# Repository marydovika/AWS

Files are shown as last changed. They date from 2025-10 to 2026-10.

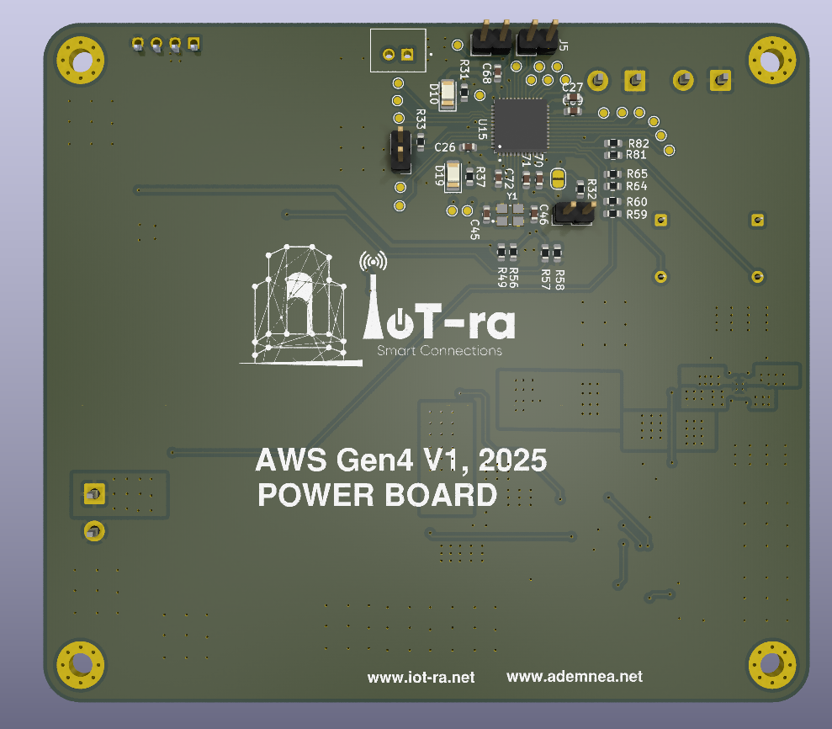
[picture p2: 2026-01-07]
IMAGES__Ver1/POWER BOARD images/Current design/BACK GREEN.png

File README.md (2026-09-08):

//////////////////////////////////////////////////////////////////////////////////////////////////

System Description:

Automatic Weather Stations (AWS) play a critical role in environmental monitoring, yet
their deployment in remote and energy-constrained locations remains limited by rigid and
monolithic power architectures.
Conventional systems are often designed for single energy sources, leading to inefficiencies, frequent power interruptions, high maintenance costs, and
poor adaptability to dynamic environmental conditions.
This research proposes the development of a modular and adaptive power electronics system architecture tailored for
energy-constrained AWS deployments.
Modular design;
The modular design introduces swappable converter topologies that allow scalable integration (multiplexing) of multiple energy sources,
including solar, DC input and  batteries, while simplifying upgrades, repairs, and fault isolation.
Adaptive design;
Complementing the modular design, an adaptive control strategy will be implemented to dynamically
optimize power flow in response to load variations, energy resource intermittency, in-system parameter drifts, and external/environmental
disturbances, thereby enhancing system stability and efficiency.
The study will involve system design, prototype development, and two algorithm development (both AMPC-based), followed by performance evaluation
under varying operating conditions and benchmarking. Field deployment of Final product (PCB, Case Unit, and Mounting frame).

Expected outcomes include;
improved system energy efficiency,
fault tolerance, and operational autonomy,
ensuring more reliable and sustainable weather data collection in energy resource-constrained and off-grid regions.
The findings of this research will contribute to advancing resilient power system solutions that support agriculture, public
safety, infrastructure planning, and climate research. with a civil and possible military adaptation.

Project is funded by:
https://www.ademneaproject.net

//////////////////////////////////////////////////////////////////////////////////////////////////

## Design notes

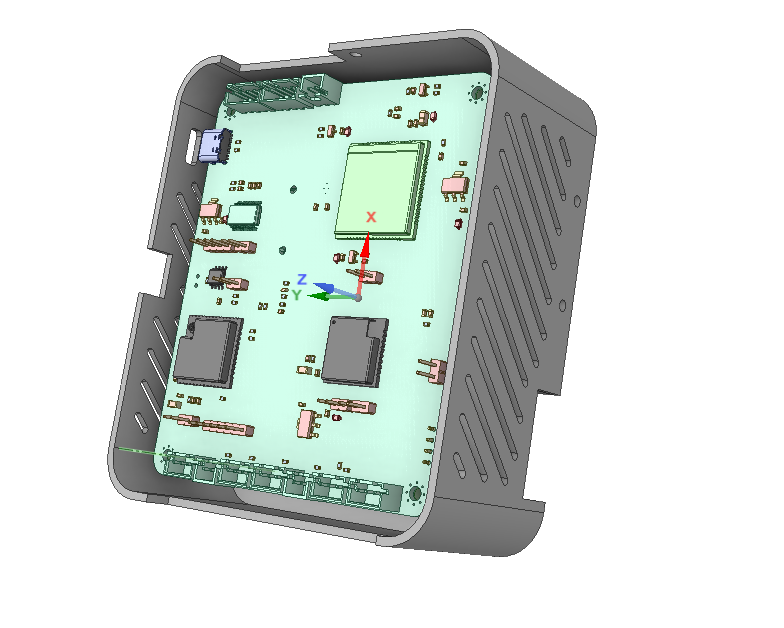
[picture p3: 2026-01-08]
IMAGES__Ver1/CASE DESIGN/design 2/Screenshot 2026-01-08 214305.png

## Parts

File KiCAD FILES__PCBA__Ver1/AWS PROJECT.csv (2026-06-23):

Reference | Qty | Value | DNP | Exclude from BOM | Exclude from Board | LCSC | Footprint | Datasheet
BT1 | 1 | BHX1-1225-PC |  |  |  | C6868959 | BHX1-1225-PC:BAT_BHX1-1225-PC
C1,C3,C30,C35,C61,C62 | 6 | 10uF |  |  |  | C19702 | Capacitor_SMD:C_0603_1608Metric | ~
C2,C4,C6,C11,C12,C13,C15,C18,C26,C27,C28,C33,C34 | 13 | 0.1uF |  |  |  | C14663 | Capacitor_SMD:C_0603_1608Metric | ~
C7,C8,C9,C16,C29,C31,C36,C63,C64 | 9 | 1uF |  |  |  | C15849 | Capacitor_SMD:C_0603_1608Metric | ~
C14 | 1 | 22uF |  |  |  | C12891 | Capacitor_SMD:C_1206_3216Metric_Pad1.33x1.80mm_HandSolder | ~
C17 | 1 | 100uF |  |  |  | C15008 | Capacitor_SMD:C_1206_3216Metric_Pad1.33x1.80mm_HandSolder | ~
C25,C47,C48 | 3 | 10uF |  |  |  | C89632 | Capacitor_SMD:C_1206_3216Metric_Pad1.33x1.80mm_HandSolder | CC0603KRX7R9BB103,~
C32 | 1 | 4.7uF |  |  |  | C1705 | Capacitor_SMD:C_0603_1608Metric | ~
C37,C49 | 2 | 2.2uF |  |  |  | C23630 | Capacitor_SMD:C_0603_1608Metric_Pad1.08x0.95mm_HandSolder | CC0603KRX7R9BB103
C38,C54 | 2 | 22pF |  |  |  | C92670 | Capacitor_SMD:C_0603_1608Metric_Pad1.08x0.95mm_HandSolder | CC0603KRX7R9BB103
C39 | 1 | 0.01uF |  |  |  | C100042 | Capacitor_SMD:C_0603_1608Metric_Pad1.08x0.95mm_HandSolder | CC0603KRX7R9BB103
C40,C41,C43,C53 | 4 | 1uF |  |  |  | C15849 | Capacitor_SMD:C_0603_1608Metric_Pad1.08x0.95mm_HandSolder | CC0603KRX7R9BB103
C42 | 1 | 0.1uf |  |  |  | C14663 | Capacitor_SMD:C_0603_1608Metric_Pad1.08x0.95mm_HandSolder | CC0603KRX7R9BB103
C44 | 1 | 10uF |  |  |  | C30110 | Capacitor_SMD:CP_Elec_5x5.8 | ~
C45 | 1 | 100nF |  |  |  | C24497 | Capacitor_SMD:C_1206_3216Metric_Pad1.33x1.80mm_HandSolder | CC1206KRX7R9BB104
C46 | 1 | 10nF |  |  |  | C100042 | Capacitor_SMD:C_0603_1608Metric_Pad1.08x0.95mm_HandSolder | CC0603KRX7R9BB103
C50 | 1 | 0.1uF |  |  |  | C14663 | Capacitor_SMD:C_0603_1608Metric_Pad1.08x0.95mm_HandSolder | CC0603KRX7R9BB103
C55 | 1 | 2.7nF |  |  |  | C107085 | Capacitor_SMD:C_0603_1608Metric | 0603B272K500NT
C56,C59,C60 | 3 | 22uF |  |  |  | C86295 | Capacitor_SMD:C_0603_1608Metric_Pad1.08x0.95mm_HandSolder | CL10A226MO7JZNC
C57 | 1 | 10uF |  |  |  | C89632 | Capacitor_SMD:C_1210_3225Metric_Pad1.33x2.70mm_HandSolder | CC0603KRX7R9BB103
C58 | 1 | 33pF |  |  |  | C107047 | Capacitor_SMD:C_0603_1608Metric | CC0603JRNPO9BN330
C65 | 1 | 0.1uF |  |  |  | C66501 | Capacitor_SMD:C_0603_1608Metric | ~
C66 | 1 | 10nF |  |  |  | C1589 | Capacitor_SMD:C_0603_1608Metric | ~
C67 | 1 | 0.1uF |  |  |  | C1592 | Capacitor_SMD:C_0603_1608Metric | ~
C68,C71 | 2 | 4.7uF |  |  |  | C19666 | Capacitor_SMD:C_0603_1608Metric | ~
C69,C70 | 2 | 0.1uF |  |  |  | C1589 | Capacitor_SMD:C_0603_1608Metric | ~
C72,C73 | 2 | 22pF |  |  |  | C92670 | Capacitor_SMD:C_0603_1608Metric | ~
D1,D2,D15,D16 | 4 | 1N5819WS |  |  | Excluded from board | C191023 | Diode_SMD:D_SOD-323 | https://datasheet.lcsc.com/lcsc/2204281430_Guangdong-Hottech-1N5819WS_C191023.pdf
D3,D4,D7,D22 | 4 | PESDHC3D3V3U |  |  |  | C41376407 | Diode_SMD:D_SOD-323F | https://www.lcsc.com/datasheet/lcsc_datasheet_2409191648_hongjiacheng-SMAJ10A_C41376407.pdf
D5,D8,D9,D11,D13,D14,D17,D18,D19,D20 | 10 | NET_LED |  |  |  | C22371297 | Diode_SMD:D_0603_1608Metric | ~
D6 | 1 | ESDA6V1W5 |  |  |  | C48677 | ESDA6V1W5:SOT65P210X110-5N
D21,D23 | 2 | B540C-13-F |  |  |  | C72264 | Diode_SMD:D_SMB-SMC_Universal_Handsoldering | ~
D24 | 1 | green |  |  |  | C2980185 | LED_SMD:LED_1206_3216Metric | ~
D25 | 1 | red |  |  |  | C28310439 | LED_SMD:LED_1206_3216Metric | ~
FB1 | 1 | FerriteBead_Small |  |  |  | C3764553 | BLM03HG601SZ1D:BEADC0603X33N | ~
GSM1,GSM2 | 2 | U.FL-R-SMT(10) |  |  |  | C434808 | Connector_Coaxial:U.FL_Molex_MCRF_73412-0110_Vertical
J7 | 1 | 104224-0820 |  |  |  | C585349 | 104224-0820:MOLEX_104224-0820
J16 | 1 | 503398-1892 |  |  |  | C428492 | 503398-1892:MOLEX_503398-1892
J24 | 1 | TYPE-C-31-M-12 |  |  |  | C165948 | TYPE-C-31-M-12:HRO_TYPE-C-31-M-12
L1 | 1 | 6.1uH |  |  |  | C2454102 | MPPT INDUCTORS:CDEP147NP-6R1MC-95 | ~
L2 | 1 | SRN6045TA-3R3Y |  |  |  | C3221229 | Inductor_SMD:L_Bourns_SRN6045TA | SRN6045TA-3R3Y
Q1,Q2,Q3 | 3 | MMBT3904 |  |  |  | C242260 | Package_TO_SOT_SMD:SOT-23 | https://www.onsemi.com/pdf/datasheet/pzt3904-d.pdf
Q4,Q7 | 2 | 2N7002 |  |  |  | C8545 | PCM_JLCPCB:Q_SOT-23 | https://www.lcsc.com/datasheet/lcsc_datasheet_2304140030_Jiangsu-Changjing-Electronics-Technology-Co---Ltd--2N7002_C8545.pdf
Q5,Q6 | 2 | NMOS |  |  |  | C604579 | NTMFS4H01NFT3G:TRANS_NVMFS5834NLWFT1G | https://ngspice.sourceforge.io/docs/ngspice-html-manual/manual.xhtml#cha_MOSFETs
R1,R24 | 2 | 0R |  |  |  | C95177 | Resistor_SMD:R_0603_1608Metric | ~
R2,R3,R5,R6,R7,R8,R13,R14,R20,R21,R25,R26,R32,R33,R38 | 15 | 4.7k |  |  |  | C99782 | Resistor_SMD:R_0603_1608Metric | ~
R4,R10,R12,R30,R34 | 5 | 10k |  |  |  | C98220 | Resistor_SMD:R_0603_1608Metric | ~
R9,R15,R16,R23,R29,R31,R35 | 7 | 1k |  |  |  | C22548 | Resistor_SMD:R_0603_1608Metric | ~
R36 | 1 | 20K |  |  |  | C105575 | Resistor_SMD:R_0603_1608Metric | ~
R37,R54,R55,R69,R71,R73,R75,R77,R79,R80,R82 | 11 | 10K |  |  |  | C98220 | Resistor_SMD:R_0603_1608Metric | ~
R39 | 1 | 120 |  |  |  | C22787 | Resistor_SMD:R_0603_1608Metric | ~
R40,R41 | 2 | 5.1k |  |  |  | C2907044 | Resistor_SMD:R_0603_1608Metric | ~
R42,R43 | 2 | 270R |  |  |  | C2907020 | Resistor_SMD:R_0603_1608Metric | ~
R44,R45 | 2 | 3.9 |  |  |  | C2930150 | Resistor_SMD:R_0603_1608Metric | ~
R46,R48 | 2 | 23.7k |  |  |  | C22912 | Resistor_SMD:R_0603_1608Metric_Pad0.98x0.95mm_HandSolder | FRC0603F5101TS
R47,R49 | 2 | 5k |  |  |  | C2828621 | Resistor_SMD:R_0603_1608Metric_Pad0.98x0.95mm_HandSolder | FRC0603F5101TS
R50 | 1 | 499K |  |  |  | C26751 | Resistor_SMD:R_0603_1608Metric | ~
R51 | 1 | 36K |  |  |  | C2930097 | Resistor_SMD:R_0603_1608Metric | ~
R52 | 1 | 25k |  |  |  | C2828637 | Resistor_SMD:R_0603_1608Metric | ~
R53 | 1 | 51.1K |  |  |  | C2933234 | Resistor_SMD:R_0603_1608Metric_Pad0.98x0.95mm_HandSolder | FRC0603F5101TS
R56 | 1 | 5.23k |  |  |  | C2930111 | Resistor_SMD:R_0603_1608Metric | ~
R57 | 1 | 7.5k |  |  |  | C2930127 | Resistor_SMD:R_0603_1608Metric | ~
R58 | 1 | 10 |  |  |  | C109318 | Resistor_SMD:R_0603_1608Metric | ~
R59 | 1 | 100 |  |  |  | C105588 | Resistor_SMD:R_0603_1608Metric | ~
R60 | 1 | 2.2 |  |  |  | C22939 | Resistor_SMD:R_0603_1608Metric | ~
R61 | 1 | 10 |  |  |  | C2933875 | Resistor_SMD:R_1812_4532Metric | ~
R62,R63,R65 | 3 | 5K1 |  |  |  | C2907044 | Resistor_SMD:R_0603_1608Metric_Pad0.98x0.95mm_HandSolder | FRC0603F5101TS
R64 | 1 | 4.22M |  |  |  | C3009313 | Resistor_SMD:R_0603_1608Metric | ~
R66 | 1 | 154k |  |  |  | C861677 | Resistor_SMD:R_0603_1608Metric | ~
R67 | 1 | 887k |  |  |  | C5126163 | Resistor_SMD:R_0603_1608Metric | ~
R68 | 1 | 162k |  |  |  | C2998114 | Resistor_SMD:R_0603_1608Metric | ~
R70 | 1 | 20k |  |  |  | C105575 | Resistor_SMD:R_0603_1608Metric | ~
R72 | 1 | 13k |  |  |  | C2906992 | Resistor_SMD:R_0603_1608Metric | ~
R74 | 1 | 1.5K |  |  |  | C22843 | Resistor_SMD:R_0603_1608Metric | ~
R76 | 1 | 2k |  |  |  | C22975 | Resistor_SMD:R_0603_1608Metric | ~
R78 | 1 | 1.2K |  |  |  | C2906976 | Resistor_SMD:R_0603_1608Metric | ~
R81 | 1 | 330 |  |  |  | C23138 | Resistor_SMD:R_0603_1608Metric | ~
TH1 | 1 | 100k |  |  |  | C5146262 | Resistor_SMD:R_1812_4532Metric | ~
U1,U2,U10,U12,U17 | 5 | AMS1117-3.3 |  |  |  | C6186 | Package_TO_SOT_SMD:SOT-223-3_TabPin2 | http://www.advanced-monolithic.com/pdf/ds1117.pdf
U3 | 1 | TXB0108RGYR |  |  |  | C194701 | TXB0108RGYR:IC_TXB0108RGYR
U4 | 1 | ESP32-WROOM-32E__4MB_HIGH_TEMP_ |  |  |  | C701344 | ESP32-WROOM-32UE_M113EH6400UH3Q0_:MODULE_ESP32-WROOM-32UE_M113EH6400UH3Q0_
U5 | 1 | SIM7000E |  |  |  | C126272 | SIM7000E:SIMCON_SIM7000E
U8 | 1 | DS3231MZ_TRL |  |  |  | C107410 | DS3231MZ_TRL:SOIC127P600X175-8N
U9 | 1 | Ai-Thinker RA-08H |  |  |  | C2991932 | RA-08H-Ai-Thinker-Symbol-Kicad-88998:RA-08H | https://docs.ai-thinker.com/_media/lora/docs/ra-08h_v1.1.0_specification.pdf
U11 | 1 | ST3485EBDR |  |  |  | C75809 | ST3485EBDR:SOIC127P600X175-8N
U13 | 1 | FT232RL-REEL |  |  |  | C8690 | FT232RL-REEL:SOP65P780X200-28N
U14 | 1 | BQ24650RVAR |  |  |  | C53712 | BQ24650RVAR:QFN50P350X350X100-17N
U15 | 1 | TPS2121RUXR |  |  |  | C485916 | TPS2121RUXR:IC_TPS2121RUXR
U16 | 1 | AP64501SP-13 |  |  |  | C2071517 | AP64501SP-13:SOIC127P600X170-9N | AP64501SP-13
U18 | 1 | STM32F401CCU6 |  |  |  | C79861 | STM32F401CCU6 (1):QFN50P700X700X60-49N
Y1 | 1 | C3E-25.000-12-3030-X-R |  |  |  | C5567192 | C3E-25.000-12-3030-X-R:XTAL_C3E-25.000-12-3030-X-R

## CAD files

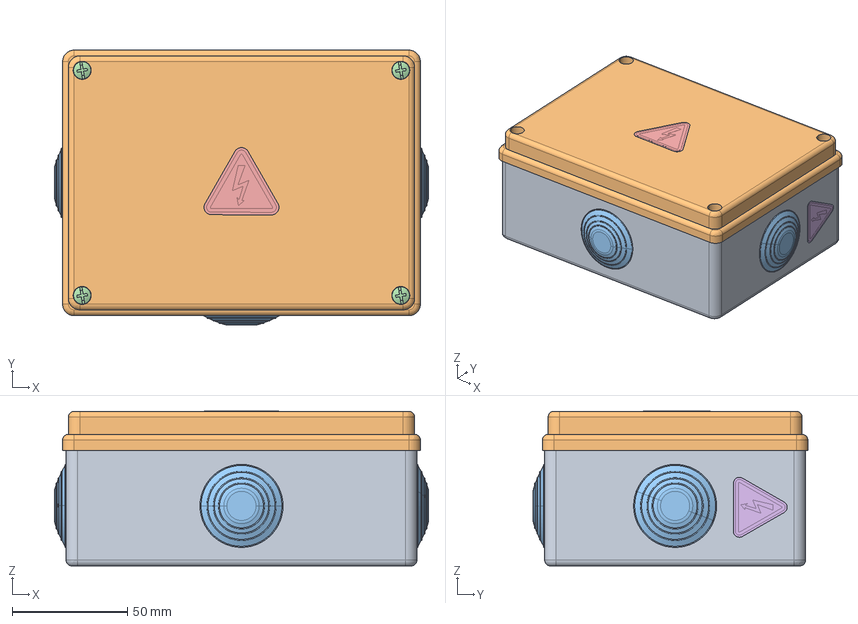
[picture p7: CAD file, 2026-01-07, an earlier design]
CAD MODELS__Ver1/junction-box-32/junction_box_asm.stp
162.0 x 119.0 x 67.1 mm
JUNCTION_BOX
JUNCTION_BOX_COVER
JUNCTION_BOX_RUBBER x 3
JUNCTION_BOX_SCREW x 4
STICKER_1
STICKER_2

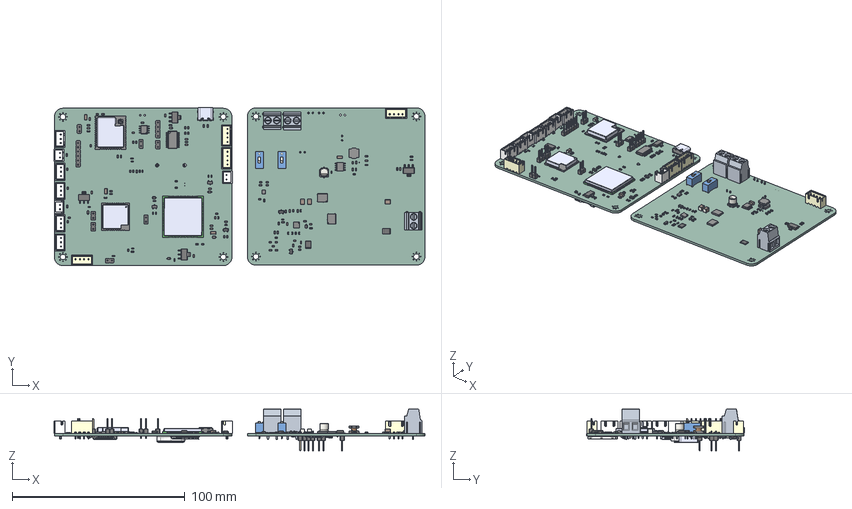
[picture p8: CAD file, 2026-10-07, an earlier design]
CAD MODELS__Ver1/AWS PROJECT 3D files.step
215.1 x 91.7 x 24.2 mm
D_SOD-323F x 4
R_0603_1608Metric x 75
PinHeader_1x02_P2.54mm_Vertical x 11
C_0603_1608Metric x 60
R_1812_4532Metric x 2
B3B-XH-A_LF__SN_ x 5
C_1210_3225Metric x 3
D_0603_1608Metric x 10
C_1206_3216Metric x 4
B4B-XH-A_LF__SN_ x 4
D_SOD-323 x 4
TB007-508-02P_Blue - S x 3
Q_SOT-23 x 2
SIM7000E
ST3485EBDR
SW_DIP_SPSTx01_Slide_9.78x4.72mm_W7.62mm_P2.54mm x 2
BQ24650RVAR
SOT-223 x 5
RA-08H--3DModel-STEP-269445
B2B-XH-A_LF__SN_ x 3
CP_Elec_5x5.8
L_Bourns_SRN6045TA
FT232RL-REEL
NTMFS4H01NFT3G x 2
PinHeader_1x06_P2.54mm_Vertical
PinHeader_1x04_P2.54mm_Vertical
SOT-23 x 3
C_0201_0603Metric
TYPE-C-31-M-12
TPS2121RUXR
ESP32-WROOM-32UE_M113EH6400UH3Q0_
AP64501SP-13
STM32F401CCU6
BHX1-1225-PC
LED_1206_3216Metric x 2
MEM2067-02-180-00-A_REVB
AWS PROJECT_PCB_1
AWS PROJECT_PCB_2

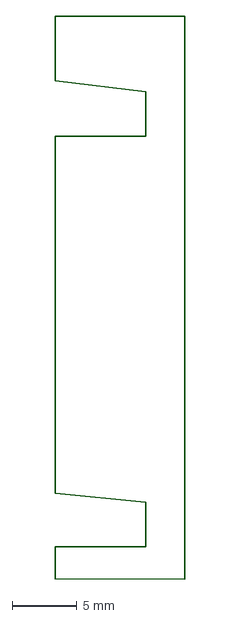
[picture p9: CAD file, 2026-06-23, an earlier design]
CAD MODELS__Ver1/prototype panel seperators/seperator.dxf
10.0 x 43.4 mm

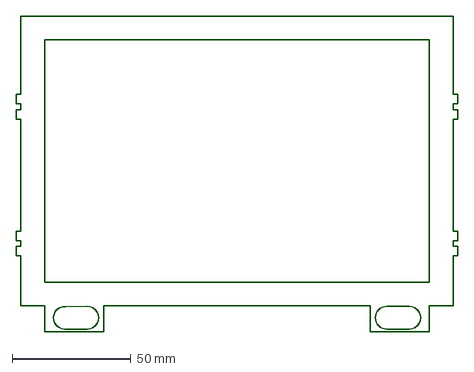
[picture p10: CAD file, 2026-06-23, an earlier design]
CAD MODELS__Ver1/prototype panel seperators/gateway acrilic.dxf
186.0 x 133.0 mm

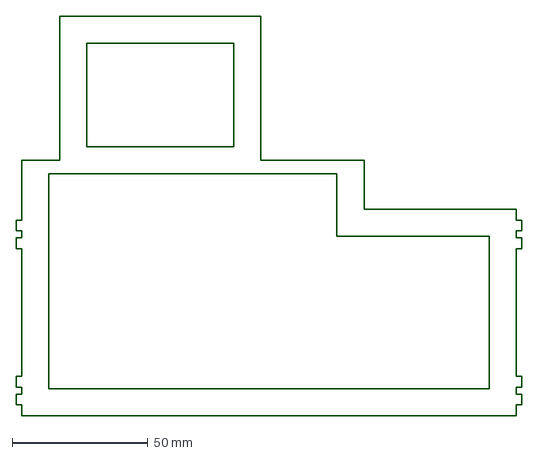
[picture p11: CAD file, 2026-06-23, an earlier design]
CAD MODELS__Ver1/prototype panel seperators/power acrilic.dxf
186.0 x 147.0 mm

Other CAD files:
CAD MODELS__Ver1/AWS PROJECT 3D ver2 files.step
CAD MODELS__Ver1/prototype panel seperators/seperator AWS.dwg

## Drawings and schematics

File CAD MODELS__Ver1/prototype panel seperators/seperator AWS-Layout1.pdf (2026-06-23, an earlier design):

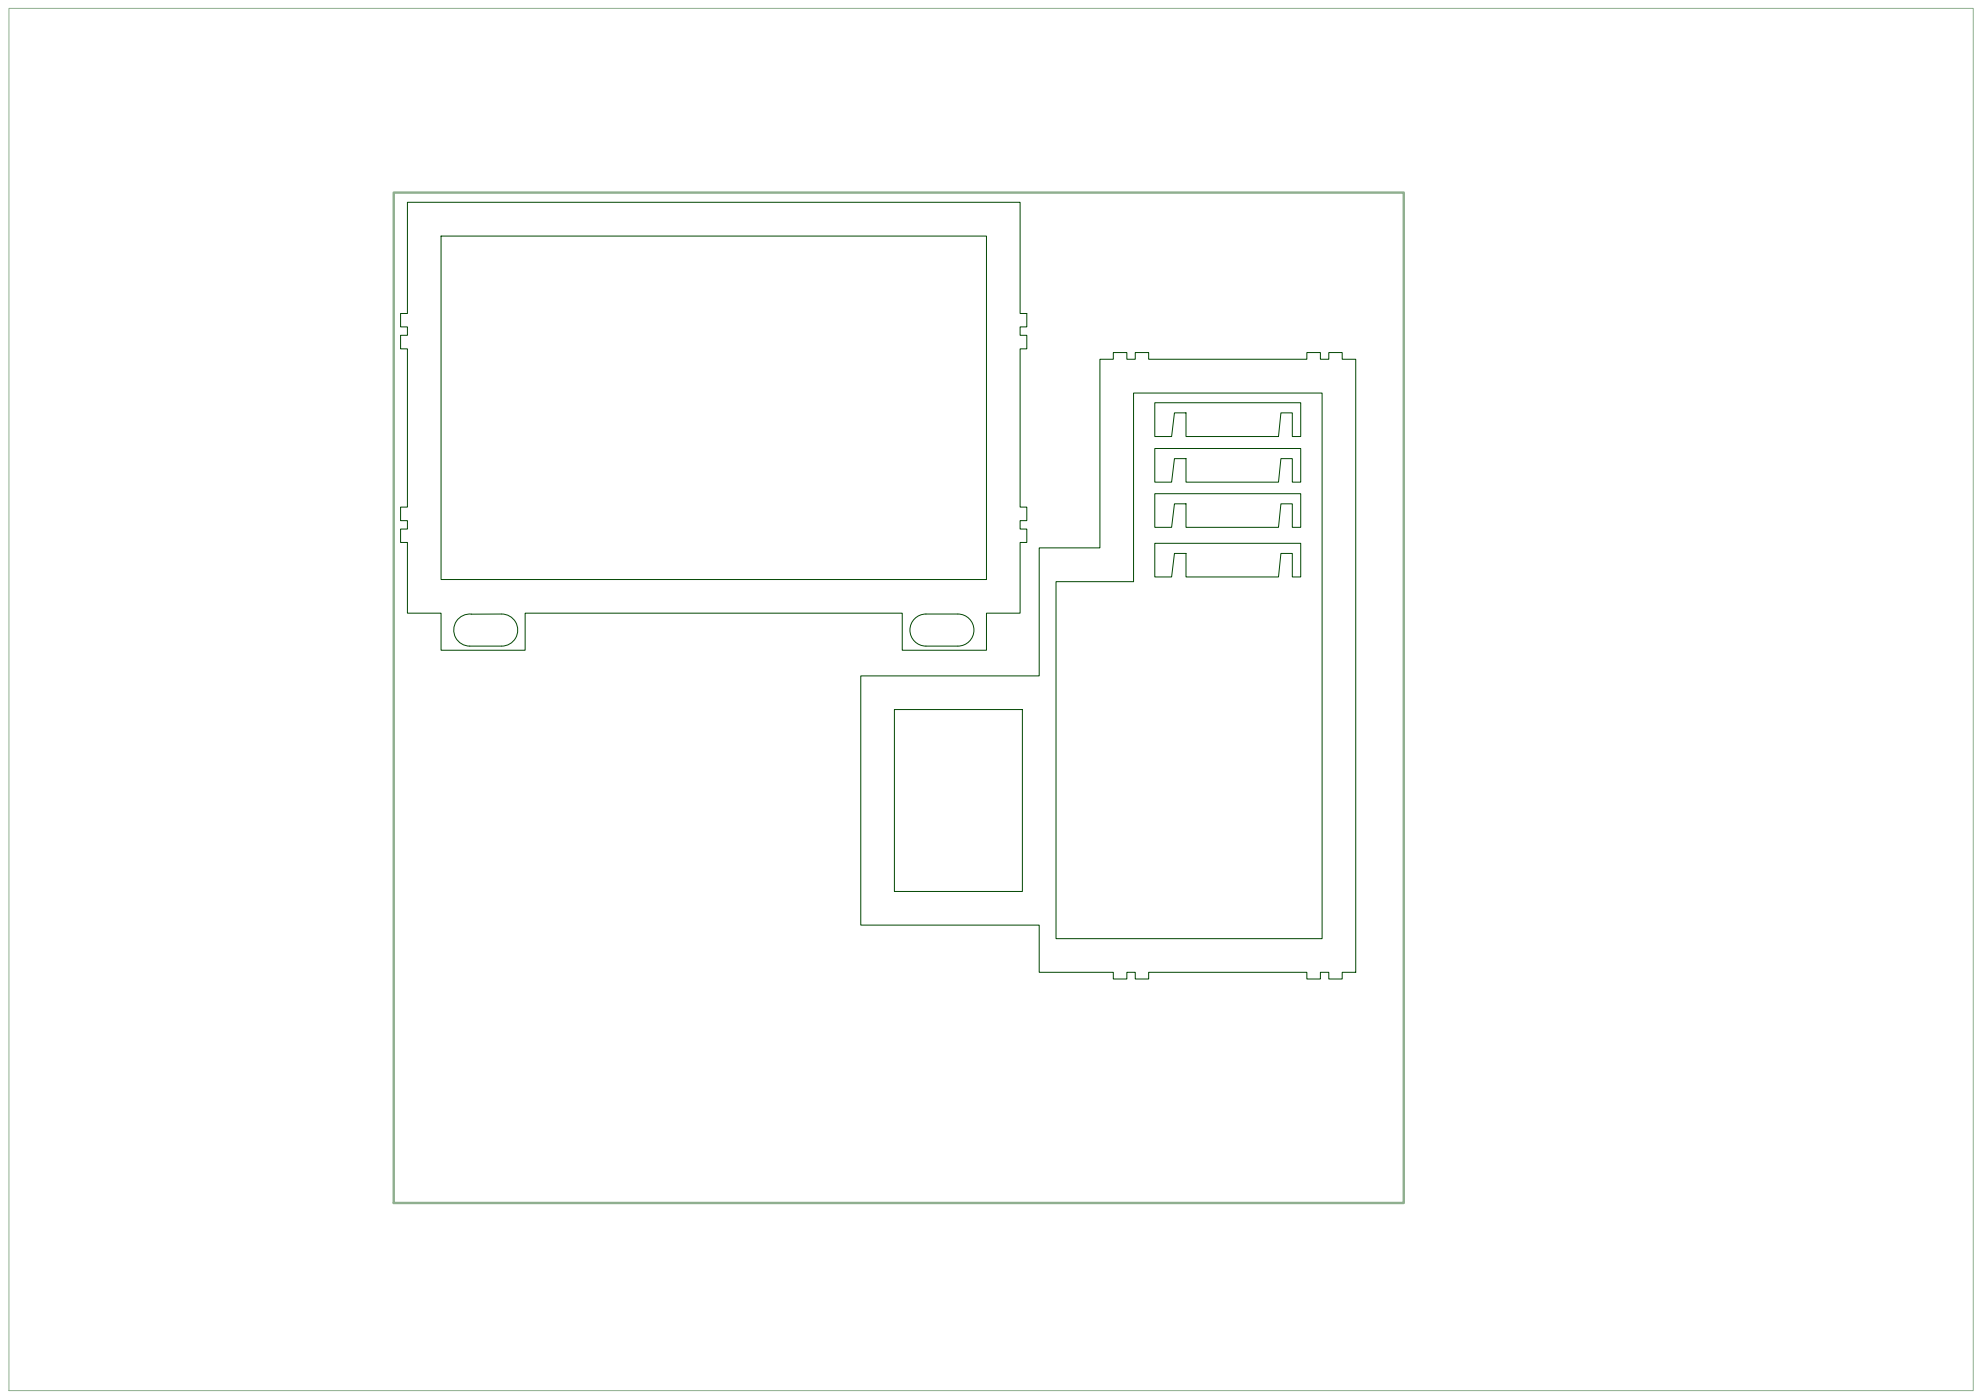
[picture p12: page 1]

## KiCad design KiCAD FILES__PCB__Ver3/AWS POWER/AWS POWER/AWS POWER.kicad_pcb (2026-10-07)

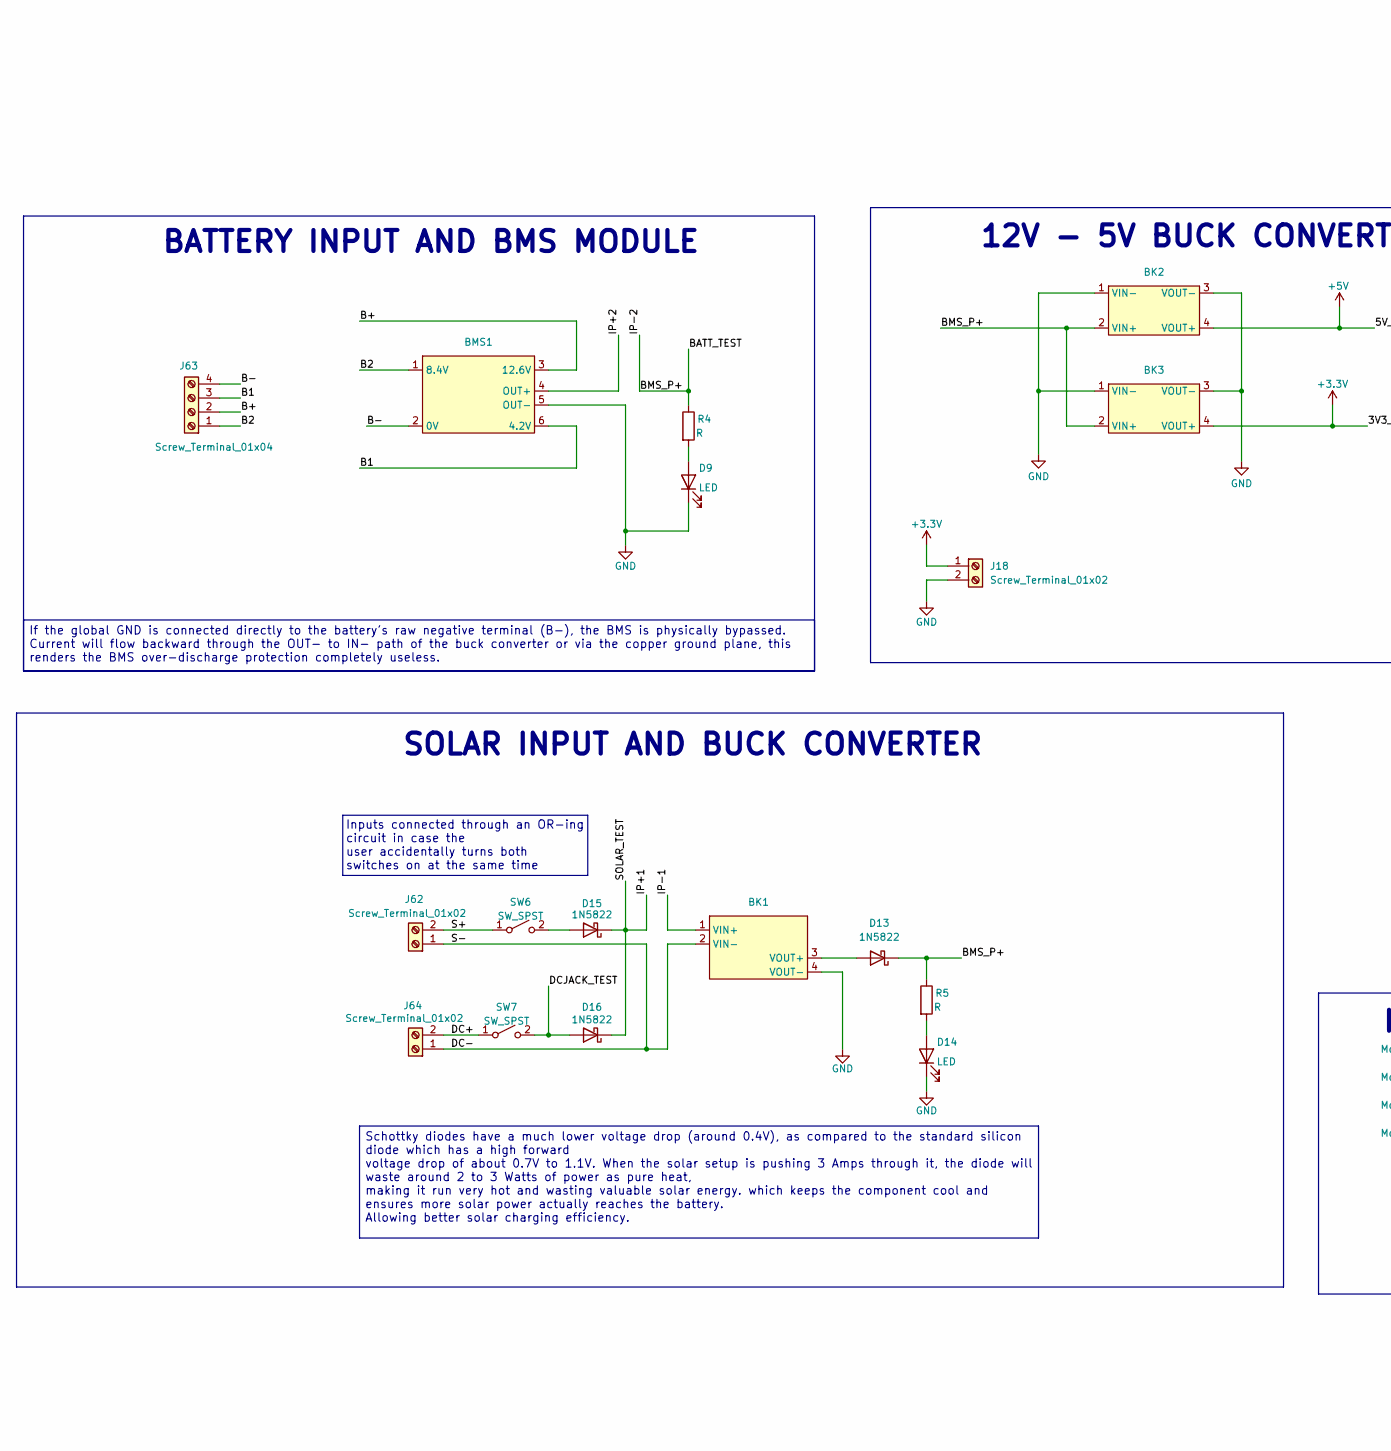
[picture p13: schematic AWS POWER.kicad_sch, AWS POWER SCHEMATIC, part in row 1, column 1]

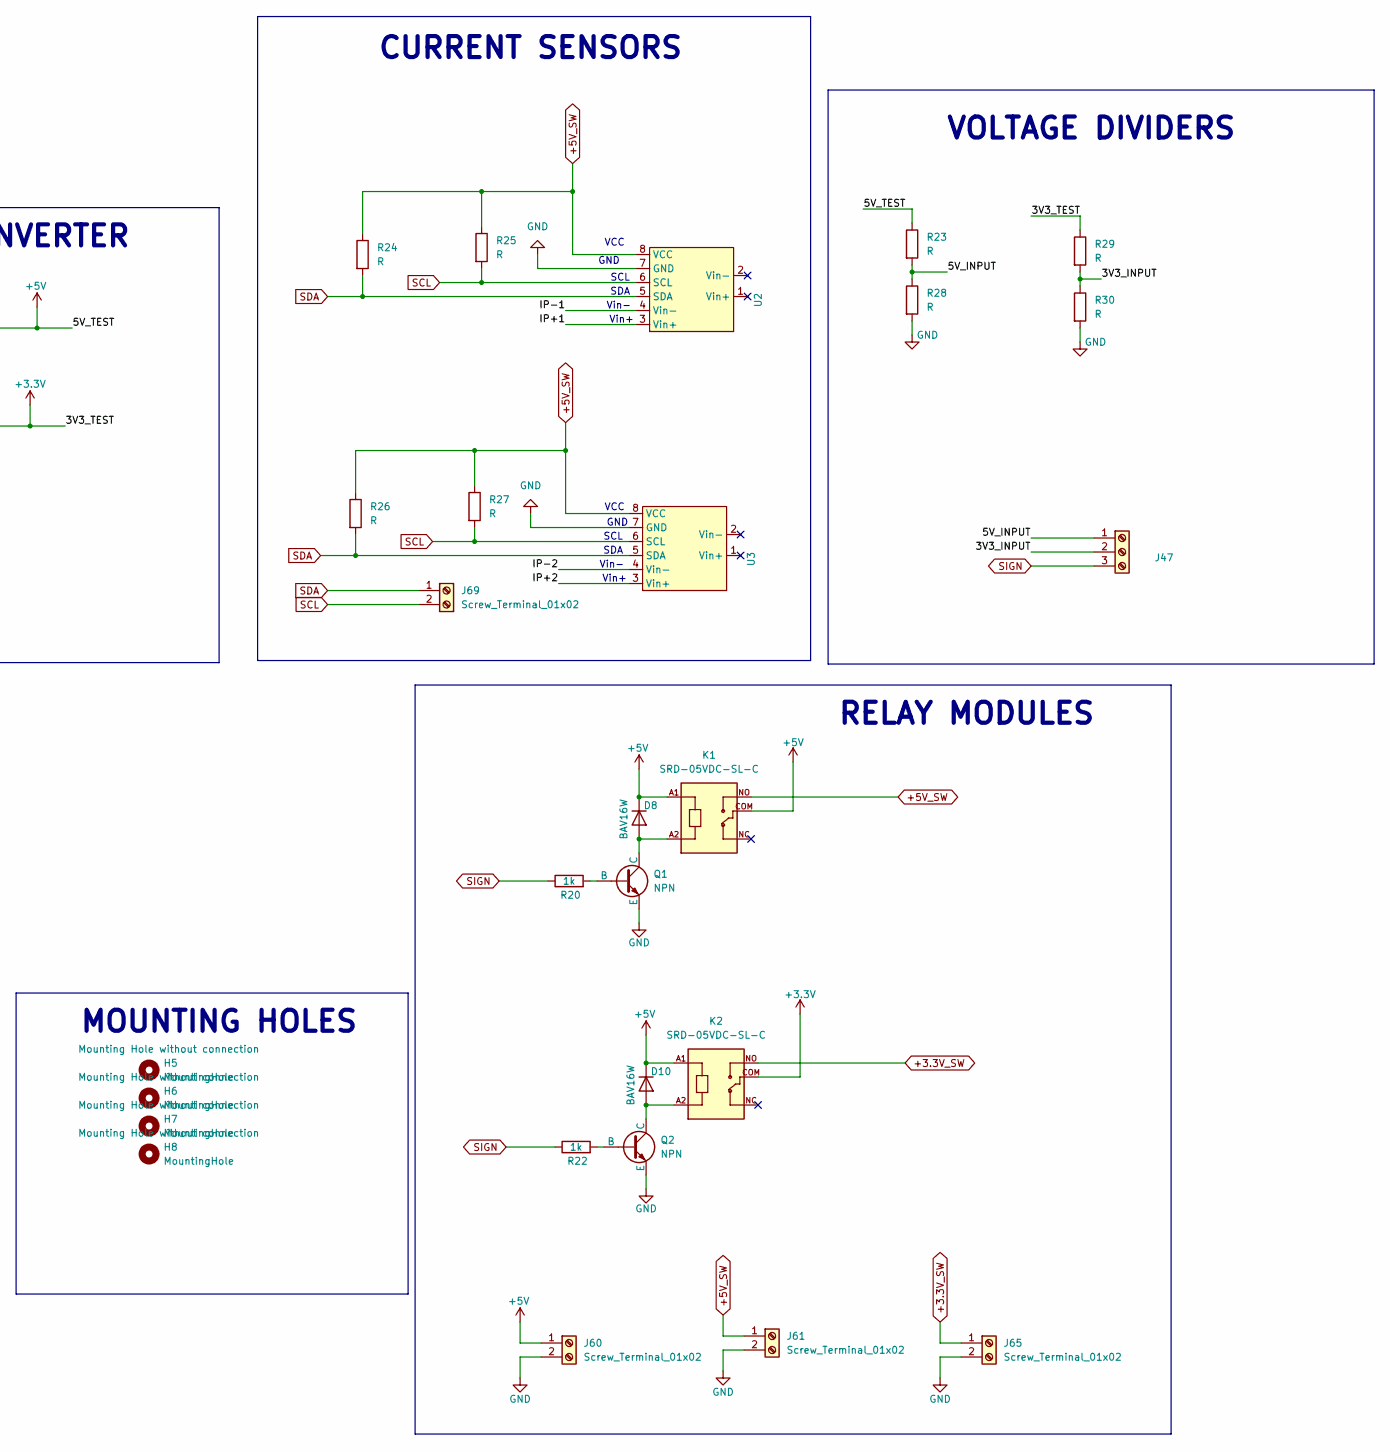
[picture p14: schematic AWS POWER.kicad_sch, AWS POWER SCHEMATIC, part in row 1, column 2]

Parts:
BK1: cn4015-2_module
BK2, BK3: MP1584 MODULE
BMS1: 3S 40A BMS
D8, D10: BAV16W; D_DO-201AD_P15.24mm_Horizontal; LCSC C459527
D9, D14: LED; LED_D3.0mm
D13, D15, D16: 1N5822; D_DO-201AD_P15.24mm_Horizontal
H5, H6, H7, H8: MountingHole; MountingHole_3.2mm_M3_DIN965_Pad_TopOnly
J18, J60, J61, J62, J64, J65, J69: Screw_Terminal_01x02; TerminalBlock_MetzConnect_Type055_RT01502HDWU_1x02_P5.00mm_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
J47: Screw_Terminal_01x03; TerminalBlock_Phoenix_MKDS-1-3-3.81_1x03_P3.81mm_Horizontal
J63: Screw_Terminal_01x04; TerminalBlock_MetzConnect_Type055_RT01504HDWU_1x04_P5.00mm_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
K1, K2: SRD-05VDC-SL-C; RELAY_SRD-05VDC-SL-C; LCSC C35449
Q1, Q2: NPN; TO-92; LCSC C52801
R4, R5, R23, R24, R25, R26, R27, R28, R29, R30: R; R_Axial_DIN0207_L6.3mm_D2.5mm_P7.62mm_Horizontal
R20, R22: 1k; R_Axial_DIN0207_L6.3mm_D2.5mm_P7.62mm_Horizontal; LCSC C22548
SW6, SW7: SW_SPST; SW_DIP_SPSTx01_Slide_9.78x4.72mm_W7.62mm_P2.54mm
U2, U3: INA219 MODULE

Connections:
+3.3V: BK3.4 (VOUT+), J18.1, K2.COM, R29.1
+3.3V_SW: J65.1, K2.NO
+5V: BK2.4 (VOUT+), D8.1 (K), D10.1 (K), J60.1, K1.A1, K1.COM, K2.A1, R23.1
+5V_SW: J61.1, K1.NO, R24.1, R25.1, R26.1, R27.1, U2.8 (VCC), U3.8 (VCC)
/3V3_INPUT: J47.2, R29.2, R30.1
/5V_INPUT: J47.1, R23.2, R28.1
/B1: BMS1.6 (4.2V), J63.3
/B2: BMS1.1 (8.4V), J63.1
/B+: BMS1.3 (12.6V), J63.2
/B-: BMS1.2 (0V), J63.4
/BATT_TEST: BK2.2 (VIN+), BK3.2 (VIN+), D13.1 (K), R4.1, R5.1, U3.4 (Vin-)
/DC+: J64.2, SW7.1 (A)
/DC-: BK1.2 (VIN-), J62.1, J64.1
/DCJACK_TEST: D16.2 (A), SW7.2 (B)
/IP+1: D15.1 (K), D16.1 (K), U2.3 (Vin+)
/IP+2: BMS1.4 (OUT+), U3.3 (Vin+)
/IP-1: BK1.1 (VIN+), U2.4 (Vin-)
/S+: J62.2, SW6.1 (A)
GND: BK1.4 (VOUT-), BK2.1 (VIN-), BK2.3 (VOUT-), BK3.1 (VIN-), BK3.3 (VOUT-), BMS1.5 (OUT-), D9.1 (K), D14.1 (K), J18.2, J60.2, J61.2, J65.2, Q1.3 (E), Q2.3 (E), R28.2, R30.2, U2.7 (GND), U3.7 (GND)
unnamed: BK1.3 (VOUT+), D13.2 (A)
unnamed: D8.2 (A), K1.A2, Q1.1 (C)
unnamed: D9.2 (A), R4.2
unnamed: D10.2 (A), K2.A2, Q2.1 (C)
unnamed: D14.2 (A), R5.2
unnamed: D15.2 (A), SW6.2 (B)
unnamed: Q1.2 (B), R20.2
unnamed: Q2.2 (B), R22.2
SCL: J69.2, R25.2, R27.2, U2.6 (SCL), U3.6 (SCL)
SDA: J69.1, R24.2, R26.2, U2.5 (SDA), U3.5 (SDA)
SIGN: J47.3, R20.1, R22.1

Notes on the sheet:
SCL
CURRENT SENSORS
Inputs connected through an OR-ing circuit in case the user accidentally turns both switches on at the same time
MOUNTING HOLES
BATTERY INPUT AND BMS MODULE
VOLTAGE DIVIDERS
GND
SOLAR INPUT AND BUCK CONVERTER
SDA
VCC
Vin-
Vin+
RELAY MODULES
12V - 5V BUCK CONVERTER
Schottky diodes have a much lower voltage drop (around 0.4V), as compared to the standard silicon diode which has a high forward voltage drop of about 0.7V to 1.1V. When the solar setup is pushing 3 Amps through it, the diode will waste around 2 to 3 Watts of power as pure heat, making it run very 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
If the global GND is connected directly to the battery's raw negative terminal (B-), the BMS is physically bypassed. Current will flow backward through the OUT- to IN- path of the buck converter or via the copper ground plane, this renders the BMS over-discharge protection completely useless.

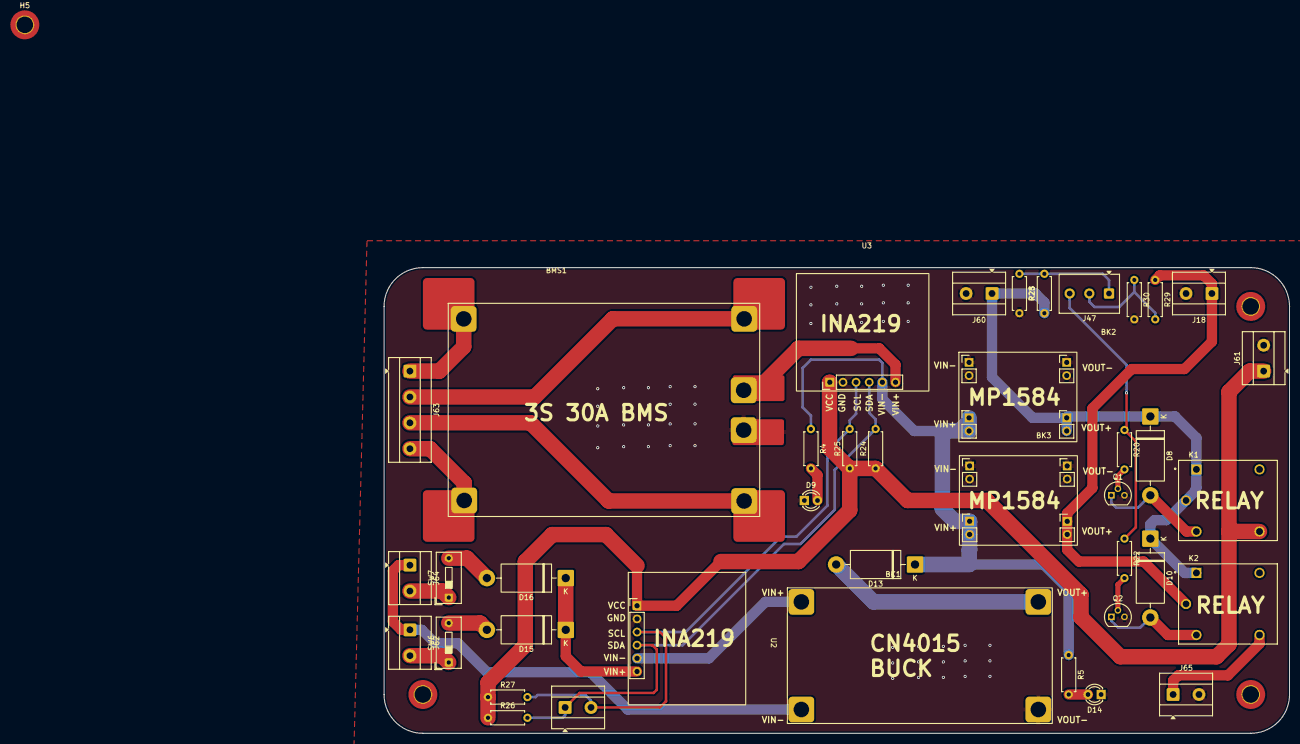
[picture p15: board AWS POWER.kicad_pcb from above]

Board: 2 copper layers, 175.0 x 90.0 mm, 44 parts (0 on the bottom side), 30 nets.

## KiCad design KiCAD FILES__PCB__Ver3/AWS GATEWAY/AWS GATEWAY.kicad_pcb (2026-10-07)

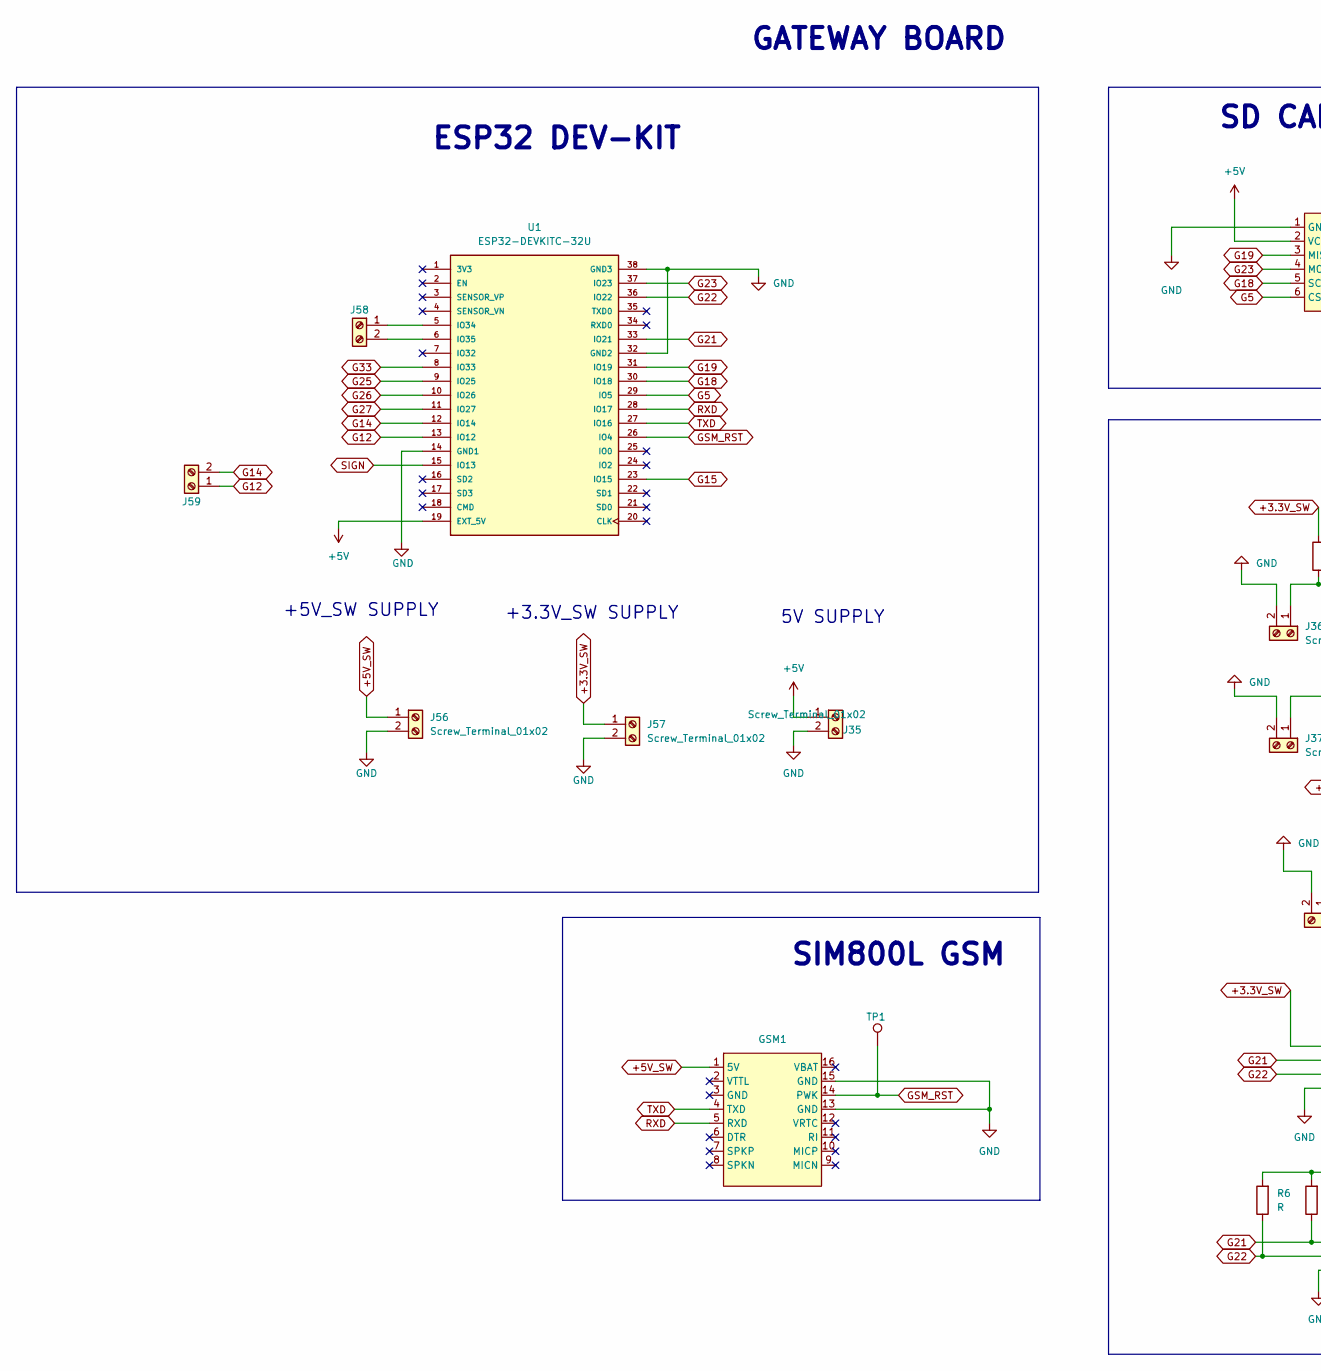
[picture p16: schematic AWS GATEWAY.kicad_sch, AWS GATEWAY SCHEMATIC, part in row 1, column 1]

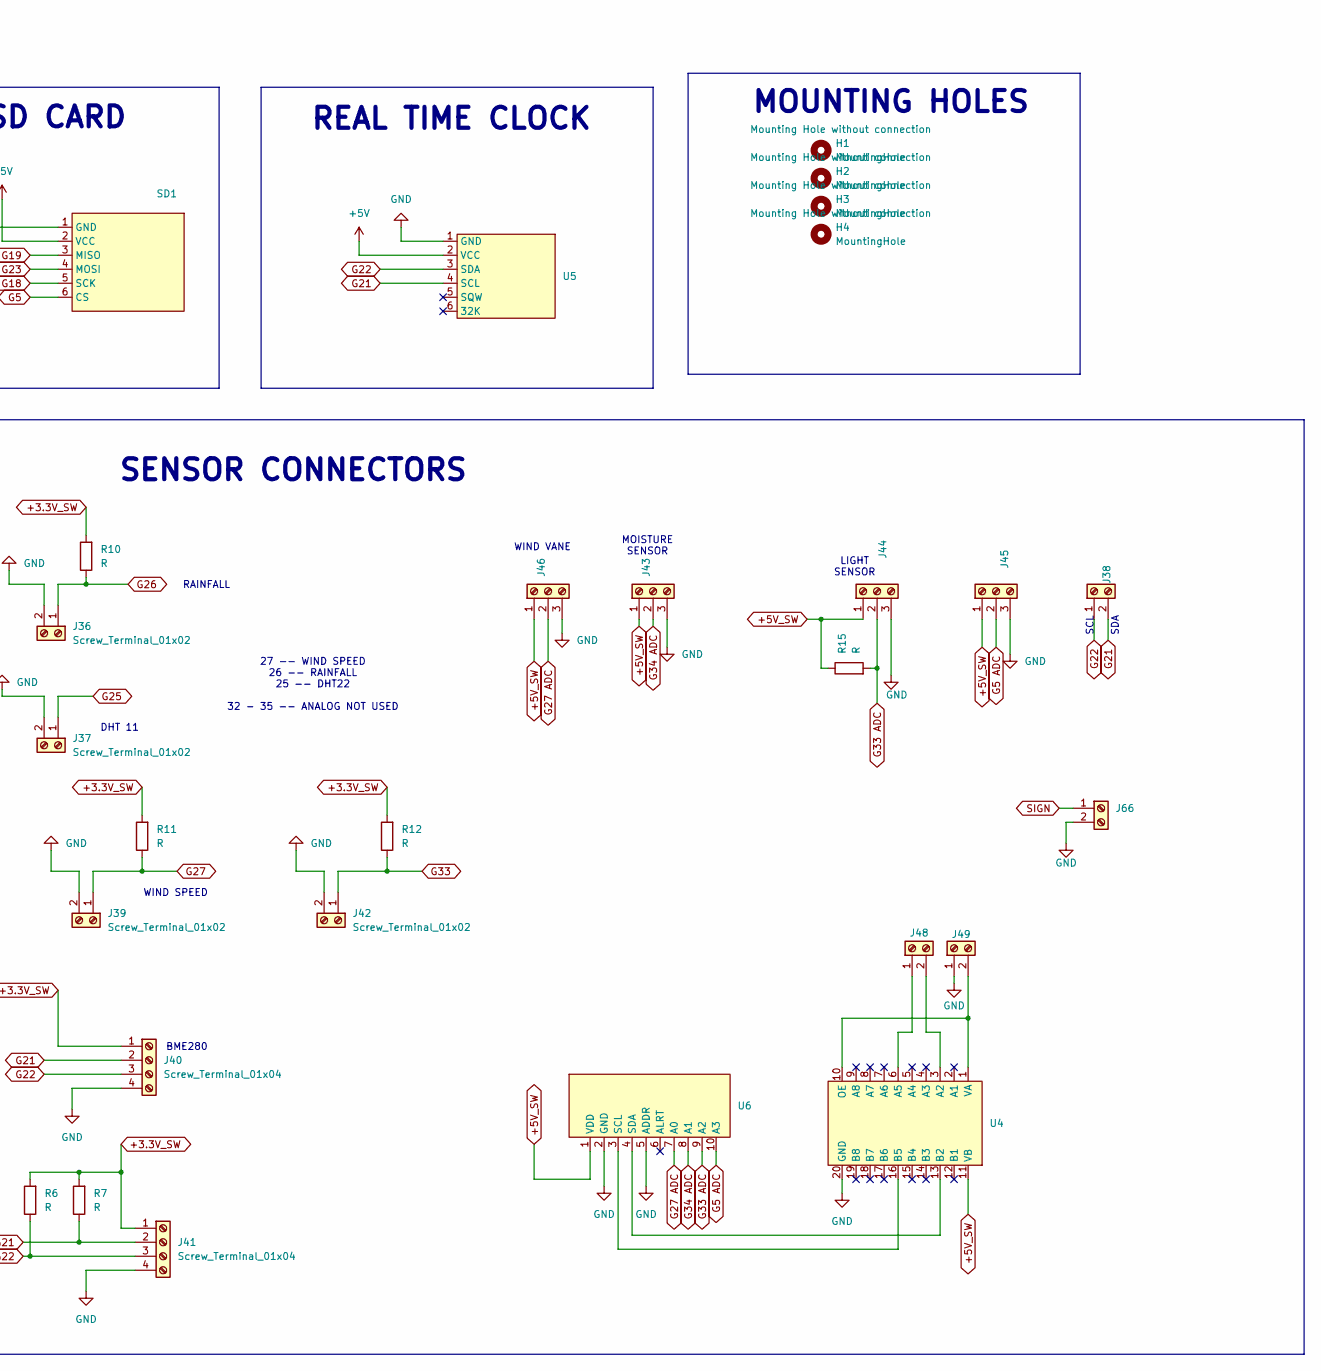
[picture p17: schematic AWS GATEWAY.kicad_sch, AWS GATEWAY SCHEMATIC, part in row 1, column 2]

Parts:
GSM1: GSM MODULE
H1, H2, H3, H4: MountingHole; MountingHole_3.2mm_M3_DIN965_Pad_TopOnly
J35, J36, J37, J38, J39, J42, J48, J49: Screw_Terminal_01x02; TerminalBlock_Phoenix_MKDS-1-2-3.81_1x02_P3.81mm_Horizontal
J40, J41: Screw_Terminal_01x04; TerminalBlock_Phoenix_MKDS-1-4-3.81_1x04_P3.81mm_Horizontal
J43, J44, J45, J46: Screw_Terminal_01x03; TerminalBlock_Phoenix_MKDS-1-3-3.81_1x03_P3.81mm_Horizontal
J56, J57, J58, J59, J66: Screw_Terminal_01x02; TerminalBlock_MetzConnect_Type055_RT01502HDWU_1x02_P5.00mm_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
R6, R7, R10, R11, R12, R15: R; R_Axial_DIN0204_L3.6mm_D1.6mm_P7.62mm_Horizontal
SD1: SD CARD MODULE
TP1: TestPoint; TestPoint_Pad_D3.0mm
U1: ESP32-DEVKITC-32U; MODULE_ESP32-DEVKITC-32U; PARTREV V4
U4: logic level shifter
U5: RTC MODULE
U6: ADS115 MODULE

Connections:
+3.3V_SW: J40.1, J41.1, J57.1, R6.2, R7.2, R10.2, R11.2, R12.2
+5V: J35.1, SD1.2 (VCC), U1.19 (EXT_5V), U5.2 (VCC)
+5V_SW: GSM1.1 (5V), J43.1, J44.1, J45.1, J46.1, J56.1, R15.1, U4.11 (VB), U6.1 (VDD)
G5: SD1.6 (CS), U1.29 (IO5)
G5 ADC: J45.2, U6.10 (A3)
G12: J59.1, U1.13 (IO12)
G14: J59.2, U1.12 (IO14)
G15: U1.23 (IO15)
G18: SD1.5 (SCK), U1.30 (IO18)
G19: SD1.3 (MISO), U1.31 (IO19)
G21: J38.2, J40.2, J41.2, R7.1, U1.33 (IO21), U5.4 (SCL)
G22: J38.1, J40.3, J41.3, R6.1, U1.36 (IO22), U5.3 (SDA)
G23: SD1.4 (MOSI), U1.37 (IO23)
G25: J37.1, U1.9 (IO25)
G26: J36.1, R10.1, U1.10 (IO26)
G27: J39.1, R11.1, U1.11 (IO27)
G27 ADC: J46.2, U6.7 (A0)
G33: J42.1, R12.1, U1.8 (IO33)
G33 ADC: J44.2, R15.2, U6.9 (A2)
G34 ADC: J43.2, U6.8 (A1)
GND: GSM1.13 (GND), GSM1.15 (GND), J35.2, J36.2, J37.2, J39.2, J40.4, J41.4, J42.2, J43.3, J44.3, J45.3, J46.3, J49.1, J56.2, J57.2, J66.2, SD1.1 (GND), U1.14 (GND1), U1.32 (GND2), U1.38 (GND3), U4.20 (GND), U5.1 (GND), U6.2 (GND), U6.5 (ADDR)
GSM_RST: GSM1.14 (PWK), TP1.1 (1_1), U1.26 (IO4)
unnamed: J48.1, U4.6 (A5)
unnamed: J48.2, U4.3 (A2)
unnamed: J49.2, U4.1 (VA), U4.10 (OE)
unnamed: J58.1, U1.5 (IO34)
unnamed: J58.2, U1.6 (IO35)
unnamed: U4.13 (B2), U6.4 (SDA)
unnamed: U4.16 (B5), U6.3 (SCL)
RXD: GSM1.5 (RXD), U1.28 (IO17)
SIGN: J66.1, U1.15 (IO13)
TXD: GSM1.4 (TXD), U1.27 (IO16)

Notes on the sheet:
GATEWAY BOARD
SENSOR CONNECTORS
MOUNTING HOLES
+5V_SW SUPPLY
SDA
MOISTURE SENSOR
SD CARD
RAINFALL
WIND VANE
LIGHT SENSOR
WIND SPEED
SCL
BME280
27 -- WIND SPEED 26 -- RAINFALL 25 -- DHT22 32 - 35 -- ANALOG NOT USED
DHT 11
REAL TIME CLOCK
ESP32 DEV-KIT
+3.3V_SW SUPPLY
5V SUPPLY
SIM800L GSM

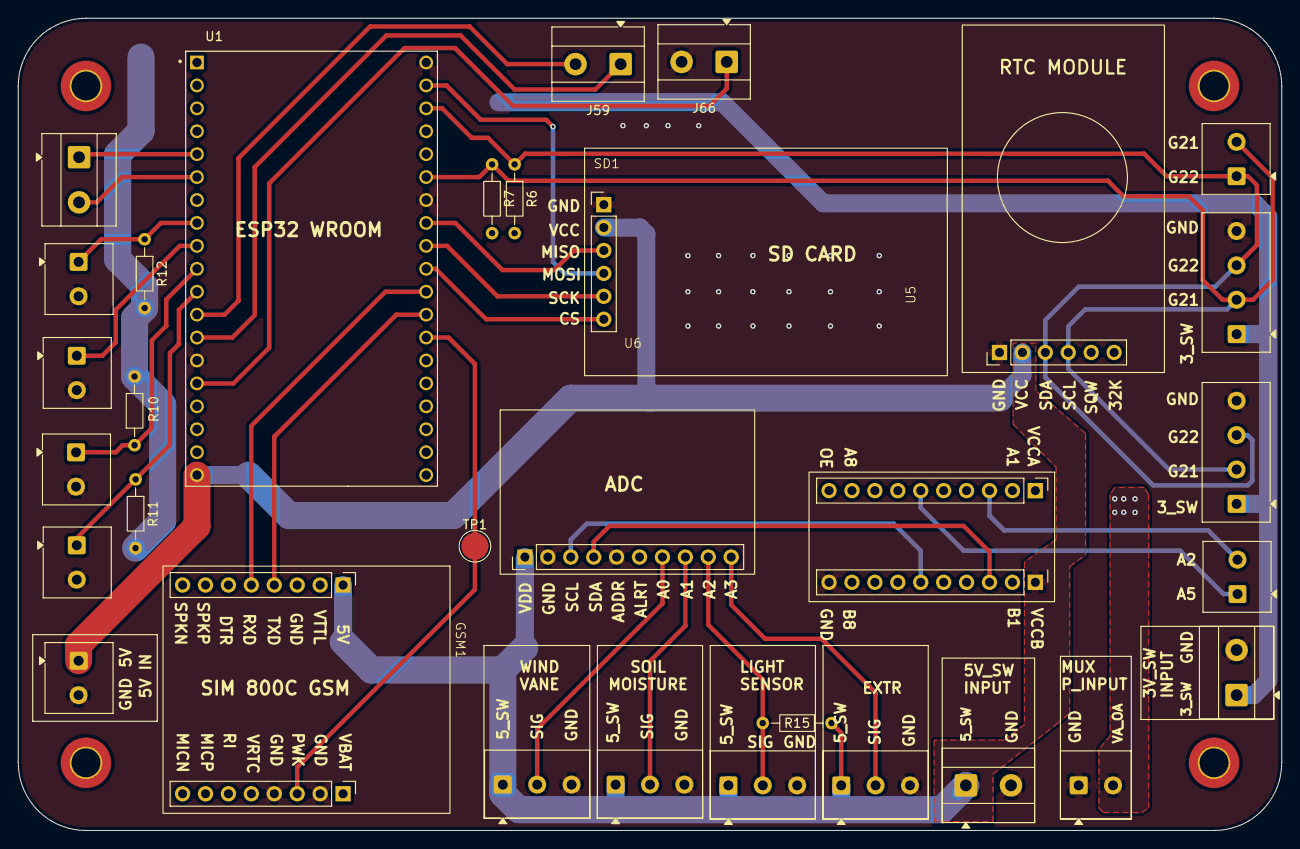
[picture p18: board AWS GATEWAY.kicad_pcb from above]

Board: 2 copper layers, 140.0 x 90.0 mm, 36 parts (0 on the bottom side), 31 nets.

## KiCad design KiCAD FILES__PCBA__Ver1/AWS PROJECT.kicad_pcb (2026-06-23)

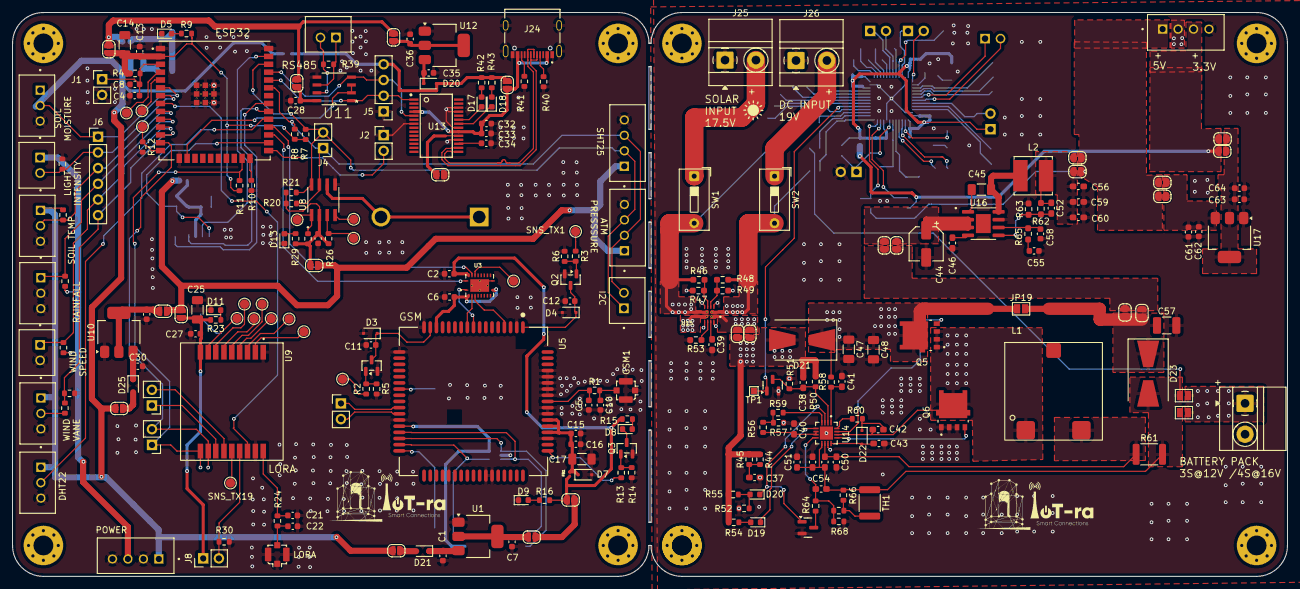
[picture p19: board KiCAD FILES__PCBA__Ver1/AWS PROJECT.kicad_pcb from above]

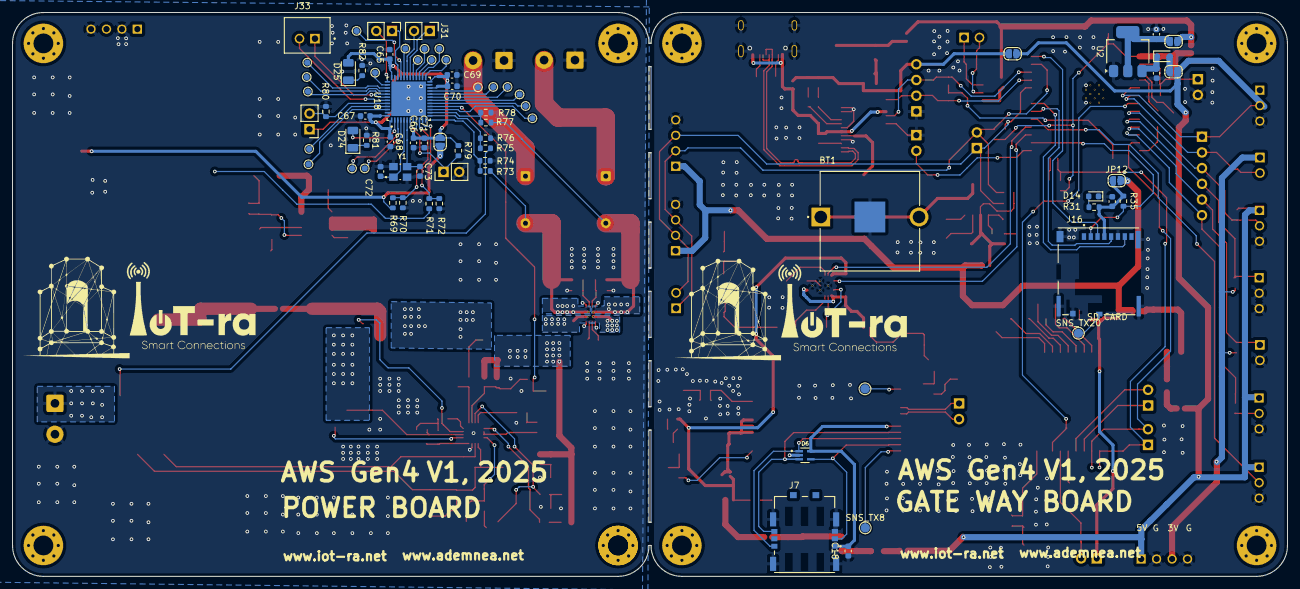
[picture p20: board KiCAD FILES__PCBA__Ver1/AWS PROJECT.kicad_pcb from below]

Board: 2 copper layers, 206.3 x 91.2 mm, 308 parts (74 on the bottom side), 199 nets.

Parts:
BT1: BHX1-1225-PC; BAT_BHX1-1225-PC
C1, C3, C30, C35, C61, C62: 10uF; C_0603_1608Metric
C2, C4, C6, C11, C12, C13, C15, C18, C26, C27, C28, C33, C34, C65, C67, C69, C70: 0.1uF; C_0603_1608Metric
C5, C10, C21, C22: Cm; C_0603_1608Metric
C7, C8, C9, C16, C29, C31, C36, C63, C64: 1uF; C_0603_1608Metric
C14: 22uF; C_1206_3216Metric_Pad1.33x1.80mm_HandSolder
C17: 100uF; C_1206_3216Metric_Pad1.33x1.80mm_HandSolder
C25, C47, C48: 10uF; C_1206_3216Metric_Pad1.33x1.80mm_HandSolder
C32, C68, C71: 4.7uF; C_0603_1608Metric
C37, C49: 2.2uF; C_0603_1608Metric_Pad1.08x0.95mm_HandSolder
C38, C54: 22pF; C_0603_1608Metric_Pad1.08x0.95mm_HandSolder
C39: 0.01uF; C_0603_1608Metric_Pad1.08x0.95mm_HandSolder
C40, C41, C43, C53: 1uF; C_0603_1608Metric_Pad1.08x0.95mm_HandSolder
C42: 0.1uf; C_0603_1608Metric_Pad1.08x0.95mm_HandSolder
C44: 10uF; CP_Elec_5x5.8
C45: 100nF; C_1206_3216Metric_Pad1.33x1.80mm_HandSolder
C46: 10nF; C_0603_1608Metric_Pad1.08x0.95mm_HandSolder
C50: 0.1uF; C_0603_1608Metric_Pad1.08x0.95mm_HandSolder
C51: 10uF; C_0603_1608Metric_Pad1.08x0.95mm_HandSolder
C52: OPEN; C_0603_1608Metric_Pad1.08x0.95mm_HandSolder
C55: 2.7nF; C_0603_1608Metric
C56, C59, C60: 22uF; C_0603_1608Metric_Pad1.08x0.95mm_HandSolder
C57: 10uF; C_1210_3225Metric_Pad1.33x2.70mm_HandSolder
C58: 33pF; C_0603_1608Metric
C66: 10nF; C_0603_1608Metric
C72, C73: 22pF; C_0603_1608Metric
D3, D4, D7, D22: PESDHC3D3V3U; D_SOD-323F
D5, D8, D9, D11, D13, D14, D17, D18, D19, D20#2: NET_LED; D_0603_1608Metric
D6: ESDA6V1W5; SOT65P210X110-5N
D20, D21, D24, D25: 1N5819WS; D_SOD-323
D21#2, D23: B540C-13-F; D_SMB-SMC_Universal_Handsoldering
D24#2: green; LED_1206_3216Metric
D25#2: red; LED_1206_3216Metric
FB1: FerriteBead_Small; BEADC0603X33N
GSM1, GSM2: U.FL-R-SMT(10); U.FL_Molex_MCRF_73412-0110_Vertical
J1, J2, J3, J4, J8, J9, J10, J29, J30, J31, J32: Conn_01x02_Pin; PinHeader_1x02_P2.54mm_Vertical
J5: Conn_01x04_Pin; PinHeader_1x04_P2.54mm_Vertical
J6: Conn_01x06_Pin; PinHeader_1x06_P2.54mm_Vertical
J7: 104224-0820; MOLEX_104224-0820
J11, J15, J17, J28: B4B-XH-A_LF__SN_; JST_B4B-XH-A_LF__SN_
J12, J18, J19, J20, J22: B3B-XH-A_LF__SN_; JST_B3B-XH-A_LF__SN_
J13, J14, J21, J23, J33: B2B-XH-A_LF__SN_; JST_B2B-XH-A_LF__SN_
J16: 503398-1892; MOLEX_503398-1892
J24: TYPE-C-31-M-12; HRO_TYPE-C-31-M-12
J25, J26, J27: Screw_Terminal_01x02; TerminalBlock_MetzConnect_Type011_RT05502HBWC_1x02_P5.00mm_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
JP1, JP2, JP3, JP4, JP5, JP6, JP8, JP9, JP10, JP10#2, JP11, JP11#2, JP12, JP12#2, JP13, JP13#2, JP14, JP15, JP16, JP17, JP18, JP18#2, JP19#3, JP20, JP21, JP22, JP23, JP24, JP25: Jumper_2_Small_Open; SolderJumper-2_P1.3mm_Open_RoundedPad1.0x1.5mm
JP19, JP19#2, JP21#2: Jumper_2_Small_Open; SolderJumper-2_P1.3mm_Open_Pad1.0x1.5mm
L1: 6.1uH; CDEP147NP-6R1MC-95
L2: SRN6045TA-3R3Y; L_Bourns_SRN6045TA
PB1, PB2, PB3, PB4, PB5, PB6, PB7, PB8, PB9, PB10, PB11, PB12, PB13, PB14, PB15, PB16, PB17, PB18, PB19, PB20, PB21: TestPoint; TestPoint_Pad_D1.0mm
Q1, Q2, Q3: MMBT3904; SOT-23
Q4, Q7: 2N7002; Q_SOT-23
Q5, Q6: NMOS; TRANS_NVMFS5834NLWFT1G
R1, R24: 0R; R_0603_1608Metric
R2, R3, R5, R6, R7, R8, R13, R14, R20, R21, R25, R26, R32, R33, R38: 4.7k; R_0603_1608Metric
R4, R10, R11, R12, R30, R34: 10k; R_0603_1608Metric
R9, R15, R16, R23, R29, R31, R35: 1k; R_0603_1608Metric
R36: 20K; R_0603_1608Metric
R37, R54, R55, R69, R71, R73, R75, R77, R79, R80, R82: 10K; R_0603_1608Metric
R39: 120; R_0603_1608Metric
R40, R41: 5.1k; R_0603_1608Metric
R42, R43: 270R; R_0603_1608Metric
R44, R45: 3.9; R_0603_1608Metric
R46, R48: 23.7k; R_0603_1608Metric_Pad0.98x0.95mm_HandSolder
R47, R49: 5k; R_0603_1608Metric_Pad0.98x0.95mm_HandSolder
R50: 499K; R_0603_1608Metric
R51: 36K; R_0603_1608Metric
R52: 25k; R_0603_1608Metric
R53: 51.1K; R_0603_1608Metric_Pad0.98x0.95mm_HandSolder
R56: 5.23k; R_0603_1608Metric
R57: 7.5k; R_0603_1608Metric
R58: 10; R_0603_1608Metric
R59: 100; R_0603_1608Metric
R60: 2.2; R_0603_1608Metric
R61: 10; R_1812_4532Metric
R62, R63, R65: 5K1; R_0603_1608Metric_Pad0.98x0.95mm_HandSolder
R64: 4.22M; R_0603_1608Metric
R66: 154k; R_0603_1608Metric
R67: 887k; R_0603_1608Metric
R68: 162k; R_0603_1608Metric
R70: 20k; R_0603_1608Metric
R72: 13k; R_0603_1608Metric
R74: 1.5K; R_0603_1608Metric
R76: 2k; R_0603_1608Metric
R78: 1.2K; R_0603_1608Metric
R81: 330; R_0603_1608Metric
SNS_TX1, SNS_TX2, SNS_TX3, SNS_TX4, SNS_TX5, SNS_TX6, SNS_TX7, SNS_TX8, SNS_TX9, SNS_TX10, SNS_TX11, SNS_TX12, SNS_TX13, SNS_TX14, SNS_TX15, SNS_TX16, SNS_TX17, SNS_TX18, SNS_TX19, SNS_TX20: TestPoint; TestPoint_Pad_D1.5mm
SW1, SW2: SW_SPST; SW_DIP_SPSTx01_Slide_9.78x4.72mm_W7.62mm_P2.54mm
TH1: 100k; R_1812_4532Metric
TP1: TestPoint; TestPoint_Pad_1.0x1.0mm
U1, U2, U10, U12, U17: AMS1117-3.3; SOT-223-3_TabPin2
U3: TXB0108RGYR; IC_TXB0108RGYR
U4: ESP32-WROOM-32E__4MB_HIGH_TEMP_; MODULE_ESP32-WROOM-32UE_M113EH6400UH3Q0_
U5: SIM7000E; SIMCON_SIM7000E
U8: DS3231MZ_TRL; SOIC127P600X175-8N
U9: Ai-Thinker RA-08H; RA-08H
U11: ST3485EBDR; SOIC127P600X175-8N
U13: FT232RL-REEL; SOP65P780X200-28N
U14: BQ24650RVAR; QFN50P350X350X100-17N
U15: TPS2121RUXR; IC_TPS2121RUXR
U16: AP64501SP-13; SOIC127P600X170-9N
U18: STM32F401CCU6; QFN50P700X700X60-49N
Y1: C3E-25.000-12-3030-X-R; XTAL_C3E-25.000-12-3030-X-R

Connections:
3v3: J14.1, J15.3, R32.2, R33.2
5v: D20.2 (A), J5.4, J15.1, J18.1, J19.1, J20.1, J22.1, JP1.2 (B), JP2.2 (B), JP10#2.1 (A), JP10#2.2 (B), JP13.2 (B), JP15.2 (B), R38.2, R42.2, R43.2
+3.3V: J28.3, JP21.2 (B), JP24.2 (B), JP25.2 (B), R69.1
+3.3V_ESP: JP4.2 (B), JP5.2 (B), JP11#2.2 (B), JP16.2 (B)
+3.3V_GSM: JP3.2 (B), JP6.2 (B)
+3.3V_LORA: J11.1, J17.1, JP8.2 (B), JP10.2 (B), JP12#2.2 (B), JP14.2 (B)
+5V: J28.1, JP9.2 (B), JP12.2 (B), JP22.2 (B), JP23.2 (B), R71.1
/gate way/32khz: R25.1, SNS_TX11.1, U8.1 (32KHZ)
/gate way/-rs485 en: U4.16 (IO13), U11.2 (~RE), U11.3 (DE)
/gate way/D+: J3.1, U5.27 (USB_DP)
/gate way/D-: J3.2, U5.28 (USB_DM)
/gate way/DAVIS 7852: J6.4, J12.1, R32.1, U4.10 (IO25)
/gate way/DHT22: J22.2, U4.29 (IO5)
/gate way/DS18B20: J6.3, J20.2, R38.1, U4.9 (IO33)
/gate way/ESP32 power in: C13.1, C14.1, JP5.1 (A), R4.1, R7.2, R8.2, R9.2, R11.1, U4.2 (3V3)
/gate way/ESP_RX: U3.20 (B1), U4.27 (IO16)
/gate way/ESP_TX: U3.18 (B2), U4.28 (IO17)
/gate way/GSM_pw in: C2.1, FB1.2, JP6.1 (A), R15.2, R16.2, U3.19 (VCCB)
/gate way/I2C SCL: J4.2, J11.3, J17.2, J23.1, R7.1, R21.1, U4.36 (IO22), U8.8 (SCL)
/gate way/I2C SDA: J4.1, J11.2, J17.3, J23.2, R8.1, R20.1, U4.33 (IO21), U8.7 (SDA)
/gate way/INSPEED VORTEX: J6.5, J13.1, R33.1, U4.11 (IO26)
/gate way/INSPEEED VANE: J6.6, R36.2, R37.2, U4.12 (IO27)
/gate way/LORA ANT: C21.1, R24.1, U9.18 (ANT)
/gate way/LORA BOOT: J8.2, R30.2, U9.15 (IO2/BOOT)
/gate way/LORA RST: U4.8 (IO32), U9.16 (RST)
/gate way/LORA_RX: J10.2, U4.13 (IO14), U9.11 (TXD/IO17)
/gate way/LORA_TX: J10.1, R11.2, U4.23 (IO15), U9.10 (LPRXD/IO60)
/gate way/RI: SNS_TX5.1, U3.17 (B3)
/gate way/RS485 power in: C28.1, JP11#2.1 (A), U11.8 (VCC)
/gate way/RTC INT: R26.1, SNS_TX10.1, U8.3 (~INT/SQW)
/gate way/RTC RST: SNS_TX9.1, U8.4 (~RST)
/gate way/RTC power input: C26.1, JP10.1 (A), R20.2, R21.2, R25.2, R26.2, R29.2, U8.2 (VCC)
/gate way/S1223: J6.2, J14.2, R34.2, U4.7 (IO35)
/gate way/SD CS: J16.2 (CD/DAT3^2), R35.1, U4.26 (IO4)
/gate way/SD power in: C29.1, J16.4 (VDD), JP12#2.1 (A), R31.2, R35.2
/gate way/SIM CLK: D6.1, J7.S3 (CLK), U5.32 (SIM_CLK)
/gate way/SIM DATA: D6.3, J7.S6 (I/O), U5.31 (SIM_DATA)
/gate way/SIM DET: SNS_TX8.1, U5.34 (SIM_DET)
/gate way/SIM RST: D6.4, J7.S2 (RST), U5.33 (SIM_RST)
/gate way/SIM VDD: C18.1, D6.5, J7.S1 (VCC), U5.30 (SIM_VDD)
/gate way/USBD+: J24.A6 (DP1), J24.B6 (DP2), U13.15 (USBDP)
/gate way/USBD-: J24.A7 (DN1), J24.B7 (DN2), U13.16 (USBDM)
/gate way/VDD_EXT: C6.1, U3.2 (VCCA), U3.10 (OE), U5.15 (VDD_EXT)
/gate way/VH400: J6.1, J19.2, U4.6 (IO34)
/gate way/VSPI-CLK: J16.5 (CLK), U4.30 (IO18)
/gate way/VSPI-MISO: J16.7 (DAT0), U4.31 (IO19)
/gate way/VSPI-MOSI: J16.3 (CMD), U4.37 (IO23)
/gate way/gsm power key: R3.1, SNS_TX1.1
/gate way/gsm reset: R2.1, SNS_TX2.1
/gate way/gsm rx: U3.3 (A2), U5.10 (RXD)
/gate way/gsm tx: U3.1 (A1), U5.9 (TXD)
/gate way/lora power in: C25.1, C27.1, J8.1, JP8.1 (A), R23.2, U9.9 (VCC)
/gate way/main ant: C5.1, R1.1, U5.60 (RF_ANT)
/gate way/netlight: R13.1, U5.52 (NETLIGHT)
/gate way/nreset: C11.1, D3.1, Q1.3 (C), U5.16 (~NRESET)
/gate way/pwkey: C12.1, D4.1, Q2.3 (C), U5.1 (~PWRKEY)
/gate way/ri: U3.4 (A3), U5.4 (RI)
/gate way/rx: J5.2, U4.34 (RXD0), U11.1 (RO), U13.1 (TXD)
/gate way/strap2: R10.1, U4.24 (IO2)
/gate way/strap12: R12.1, SNS_TX7.1, U4.14 (IO12)
/gate way/tx: J5.3, U4.35 (TXD0), U11.4 (DI), U13.5 (RXD)
/power board/3V3_INPUT: R69.2, R70.1, U18.10 (PA0)
/power board/5V_INPUT: R71.2, R72.1, U18.11 (PA1)
/power board/BATTERY BMS: J27.1, JP19.2 (B), JP21#2.2 (B)
/power board/BATT_INPUT: R75.2, R76.1, U18.13 (PA3)
/power board/BATT_VAL: C49.2, C51.1, C53.1, C54.1, D23.2 (A), JP21#2.1 (A), R61.2, R66.2, R75.1, TH1.1, U14.9 (SRN)
/power board/BOOT0_MCU: J30.2, R80.2, U18.44 (BOOT0)
/power board/BOOT1_MCU: PB21.1, U18.20 (PB2)
/power board/CE: Q4.1 (G), TP1.1, U18.16 (PA6)
/power board/DC JACK INPUT: R48.1, R73.1, SW2.2 (B), U15.2 (IN2), U15.2_1 (IN2)
/power board/DC_INPUT: R73.2, R74.1, U18.12 (PA2)
/power board/FB: C52.2, R62.2, R63.1, U16.5 (FB)
/power board/MCU_SCL: J33.1, U18.42 (PB6)
/power board/MCU_SDA: J33.2, U18.43 (PB7)
/power board/MUXOUT: C38.1, D21#2.2 (A), JP13#2.2 (B), JP18.2 (B), R44.2, R45.2, R50.2, R54.2, R55.2
/power board/OV1: R46.2, R47.1, U15.5 (OV1)
/power board/OV2: R48.2, R49.1, U15.4 (OV2)
/power board/RST_MCU: J29.1, R79.1, U18.7 (~RST)
/power board/SOLAR INPUT: R46.1, R77.1, SW1.2 (B), U15.7 (IN1), U15.7_1 (IN1)
/power board/SOLAR_INPUT: R77.2, R78.1, U18.14 (PA4)
/power board/SW_AP: C45.1, L2.1, U16.8 (SW)
/power board/btst: R60.2, U14.16 (BTST)
/power board/cin: C72.2, U18.5 (PH0-OSC_IN), Y1.1
/power board/cout: C73.2, U18.6 (PH1-OSC_OUT), Y1.3
/power board/hidriv: Q5.4 (G), U14.15 (HIDRV)
/power board/lodriv: Q6.4 (G), U14.13 (LODRV)
/power board/mpptset: C38.2, Q4.3 (D), R50.1, R51.2, U14.2 (MPPSET)
/power board/ph: C42.2, L1.1, Q5.1 (S), Q5.2 (S), Q5.3 (S), Q6.5_6 (D), U14.14 (PH)
/power board/regn: C43.1, D22.2, U14.12 (REGN)
/power board/srp: C49.1, C50.1, L1.2, R61.1, U14.10 (SRP)
/power board/stat1: D19.1 (K), U14.5 (STAT2)
/power board/stat2: D20#2.1 (K), Q7.1 (G), U14.3 (STAT1)
/power board/ts: R59.2, U14.4 (TS)
/power board/vfb: C54.2, R64.2, R67.1, R68.2, U14.8 (VFB)
/power board/vref: C40.1, R56.2, U14.6 (VREF), U14.7 (TERM_EN)
GND: BT1.2, C1.2, C2.2, C3.2, C4.1, C5.2, C6.2, C7.2, C8.2, C9.2, C10.2, C11.2, C12.2, C13.2, C14.2, C15.2, C16.2, C17.2, C18.2, C21.2, C22.2, C25.2, C26.2, C27.2, C28.2, C29.2, C30.2, C31.2, C32.2, C33.2, C34.2, C35.2, C36.2, C37.2, C39.2, C40.2, C41.2, C43.2, C44.2, C46.2, C47.2, C48.2, C50.2, C51.2, C53.2, C55.2, C56.2, C57.2, C58.2, C59.2, C60.2, C61.2, C62.2, C63.2, C64.2, C65.2, C66.2, C67.2, C68.2, C69.2, C70.2, C71.2, C72.1, C73.1, D3.2, D4.2, D5.1 (K), D6.2, D7.2, D9.1 (K), D11.1 (K), D13.1 (K), D14.1 (K), GSM1.2, GSM2.2, J1.2, J2.1, J5.1, J7.G1 (GND), J7.G2 (GND), J7.G3 (GND), J7.G4 (GND), J7.S4 (GND), J11.4, J12.2, J12.3, J13.2, J15.2, J15.4, J16.6 (VSS), J16.9 (VSS), J16.P1 (SHIELD), J16.P2 (SHIELD), J16.P3 (SHIELD), J16.P4 (SHIELD), J17.4, J18.3, J19.3, J20.3, J22.3, J24.A1_B12 (GND), J24.B1_A12 (GND), J24.S1 (SHIELD), J24.S2 (SHIELD), J24.S3 (SHIELD), J24.S4 (SHIELD), J25.1, J26.1, J27.2, J28.2, J28.4, J29.2, JP17.2 (B), Q1.2 (E), Q2.2 (E), Q3.2 (E), Q4.2 (S), Q6.1 (S), Q6.2 (S), Q6.3 (S), Q7.2 (S), R5.1, R6.1, R10.2, R12.2, R14.1, R30.1, R34.1, R36.1, R40.1, R41.1, R47.2, R49.2, R51.1, R52.1, R53.2, R57.1, R63.2, R68.1, R70.2, R72.2, R74.2, R76.2, R78.2, R80.1, R81.1, R82.1, U1.1 (GND), U2.1 (GND), U3.11 (GND), U3.21 (EXP), U3.21_1 (EXP), U3.21_2 (EXP), U3.21_3 (EXP), U3.21_4 (EXP), U4.1 (GND), U4.15 (GND), U4.38 (GND), U4.39_1 (GND), U4.39_2 (GND), U4.39_3 (GND), U4.39_4 (GND), U4.39_5 (GND), U4.39_6 (GND), U4.39_7 (GND), U4.39_8 (GND), U4.39_9 (GND), U5.2 (GND), U5.17 (GND), U5.18 (GND), U5.29 (GND), U5.39 (GND), U5.45 (GND), U5.46 (GND), U5.54 (GND), U5.58 (GND), U5.59 (GND), U5.61 (GND), U5.62 (GND), U5.63 (GND), U5.64 (GND), U5.65 (GND), U8.5 (GND), U9.1 (GND), U9.17 (GND), U10.1 (GND), U11.5 (GND), U12.1 (GND), U13.7 (GND), U13.18 (GND), U13.21 (GND), U13.25 (AGND), U13.26 (TEST), U14.11 (GND), U14.17 (EP), U15.3 (CP2), U15.6 (PR1), U15.9 (ST), U15.12 (GND), U16.7 (GND), U17.1 (GND), U18.8 (VSSA/VREF-), U18.23 (VSS), U18.35 (VSS), U18.47 (VSS), U18.49 (EXP), Y1.2 (GND), Y1.4 (GND)
unnamed: C10.1, GSM1.1, R1.2
unnamed: C15.1, C16.1, C17.1, D7.1, FB1.1, U5.55 (VBAT), U5.56 (VBAT), U5.57 (VBAT)
unnamed: C22.1, GSM2.1, R24.2
unnamed: C37.1, R44.1, R45.1
unnamed: C42.1, D22.1, R60.1
unnamed: C55.1, R65.1
unnamed: D5.2 (A), R9.1
unnamed: D8.2 (A), R15.1
unnamed: D8.1 (K), Q3.3 (C)
unnamed: D9.2 (A), R16.1
unnamed: D11.2 (A), R23.1
unnamed: D13.2 (A), R29.1
unnamed: D14.2 (A), R31.1
unnamed: D17.2 (A), R42.1
unnamed: D17.1 (K), U13.23 (CBUS0)
unnamed: D18.2 (A), R43.1
unnamed: D18.1 (K), U13.22 (CBUS1)
unnamed: D19.2 (A), R54.1
unnamed: D20#2.2 (A), R52.2, R55.1
unnamed: C47.1, C48.1, C57.1, D21#2.1 (K), D23.1 (K), JP18#2.1 (A), JP19#2.1 (A), JP19#2.2 (B), JP20.1 (A), Q5.5_6 (D), R58.2
unnamed: D24#2.2 (A), U18.2 (PC13)
unnamed: D24#2.1 (K), R81.2
unnamed: D25.2 (A), JP13.1 (A)
unnamed: D25#2.1 (K), R82.2
unnamed: C4.2, C8.1, J1.1, R4.2, U4.3 (EN)
unnamed: J2.2, U4.25 (IO0)
unnamed: J9.1, U9.12 (RXD/IO16)
unnamed: J9.2, U9.13 (IO15)
unnamed: J16.10 (DETECT_SWITCH), SNS_TX20.1
unnamed: J18.2, R37.1
unnamed: J24.A5 (CC1), R40.2
unnamed: J24.B5 (CC2), R41.2
unnamed: J25.2, SW1.1 (A)
unnamed: J26.2, SW2.1 (A)
unnamed: J31.1, U18.30 (PA9)
unnamed: J31.2, U18.31 (PA10)
unnamed: J32.1, U18.34 (PA13/JTMS-SWDIO)
unnamed: J32.2, U18.37 (PA14/JTCK-SWCLK)
unnamed: D24.2 (A), JP2.1 (A)
unnamed: C7.1, JP3.1 (A), U1.2 (VO)
unnamed: C9.1, JP4.1 (A), U2.2 (VO)
unnamed: JP13#2.1 (A), JP18.1 (A), U15.1 (OUT), U15.1_1 (OUT), U15.8 (OUT), U15.8_1 (OUT)
unnamed: C31.1, JP14.1 (A), U10.2 (VO)
unnamed: C36.1, JP16.1 (A), U12.2 (VO)
unnamed: JP17.1 (A), U13.19 (~RESET)
unnamed: C44.1, JP19#3.1 (A), U16.2 (VIN), U16.3 (EN)
unnamed: C52.1, C56.1, C59.1, C60.1, JP22.1 (A), L2.2, R62.1
unnamed: C61.1, C62.1, JP23.1 (A), U17.3 (VI)
unnamed: C63.1, C64.1, JP24.1 (A), U17.2 (VO)
unnamed: Q1.1 (B), R2.2, R5.2
unnamed: Q2.1 (B), R3.2, R6.2
unnamed: Q3.1 (B), R13.2, R14.2
unnamed: Q7.3 (D), R64.1
unnamed: R56.1, R57.2, R59.1
unnamed: R66.1, R67.2, TH1.2
unnamed: C1.1, D21.1 (K), U1.3 (VI)
unnamed: C3.1, D24.1 (K), U2.3 (VI)
unnamed: SNS_TX4.1, U4.5 (SENSOR_VN)
unnamed: SNS_TX3.1, U4.4 (SENSOR_VP)
unnamed: SNS_TX6.1, U5.24 (USB_VBUS)
unnamed: BT1.1, BT1.1_1, U8.6 (VBAT)
unnamed: SNS_TX17.1, U9.5 (IO4)
unnamed: SNS_TX18.1, U9.6 (IO5)
unnamed: SNS_TX14.1, U9.2 (IO8)
unnamed: SNS_TX16.1, U9.4 (IO9)
unnamed: SNS_TX15.1, U9.3 (IO11)
unnamed: SNS_TX19.1, U9.14 (IO14)
unnamed: SNS_TX12.1, U9.7 (SWC/IO7)
unnamed: SNS_TX13.1, U9.8 (SWD/IO6)
unnamed: C30.1, D25.1 (K), U10.3 (VI)
unnamed: J21.1, R39.2, U11.6 (A)
unnamed: J21.2, R39.1, U11.7 (B)
unnamed: C35.1, U12.3 (VI)
unnamed: C34.1, U13.17 (3V3OUT)
unnamed: C41.1, R58.1, U14.1 (VCC)
unnamed: R53.1, U15.10 (ILIM)
unnamed: C39.1, U15.11 (SS)
unnamed: C45.2, U16.1 (BST)
unnamed: C58.1, R65.2, U16.6 (COMP)
unnamed: C46.1, U16.4 (SS)
unnamed: PB1.1, U18.15 (PA5)
unnamed: PB2.1, U18.17 (PA7)
unnamed: PB3.1, U18.29 (PA8)
unnamed: PB5.1, U18.32 (PA11)
unnamed: PB4.1, U18.33 (PA12)
unnamed: PB6.1, U18.38 (PA15/JTDI)
unnamed: PB7.1, U18.18 (PB0)
unnamed: PB8.1, U18.19 (PB1)
unnamed: PB9.1, U18.39 (PB3/JTDO-SWO)
unnamed: PB10.1, U18.40 (PB4/~JTRST)
unnamed: PB11.1, U18.41 (PB5)
unnamed: PB12.1, U18.45 (PB8)
unnamed: PB13.1, U18.46 (PB9)
unnamed: PB14.1, U18.21 (PB10)
unnamed: PB15.1, U18.25 (PB12)
unnamed: PB16.1, U18.26 (PB13)
unnamed: PB17.1, U18.27 (PB14)
unnamed: PB18.1, U18.28 (PB15)
unnamed: PB19.1, U18.3 (PC14-OSC32_IN)
unnamed: PB20.1, U18.4 (PC15-OSC32_OUT)
VBUS: C32.1, C33.1, J24.A4_B9 (VBUS), J24.B4_A9 (VBUS), JP15.1 (A), U13.4 (VCCIO), U13.20 (VCC)
VDD: C65.1, C66.1, C67.1, C68.1, C69.1, C70.1, C71.1, D25#2.2 (A), J30.1, JP25.1 (A), R79.2, U18.1 (VBAT), U18.9 (VDDA/VREF+), U18.22 (VCAP_1), U18.24 (VDD), U18.36 (VDD), U18.48 (VDD)
Vbuck: JP11.2 (B), JP18#2.2 (B), JP19#3.2 (B), JP20.2 (B)

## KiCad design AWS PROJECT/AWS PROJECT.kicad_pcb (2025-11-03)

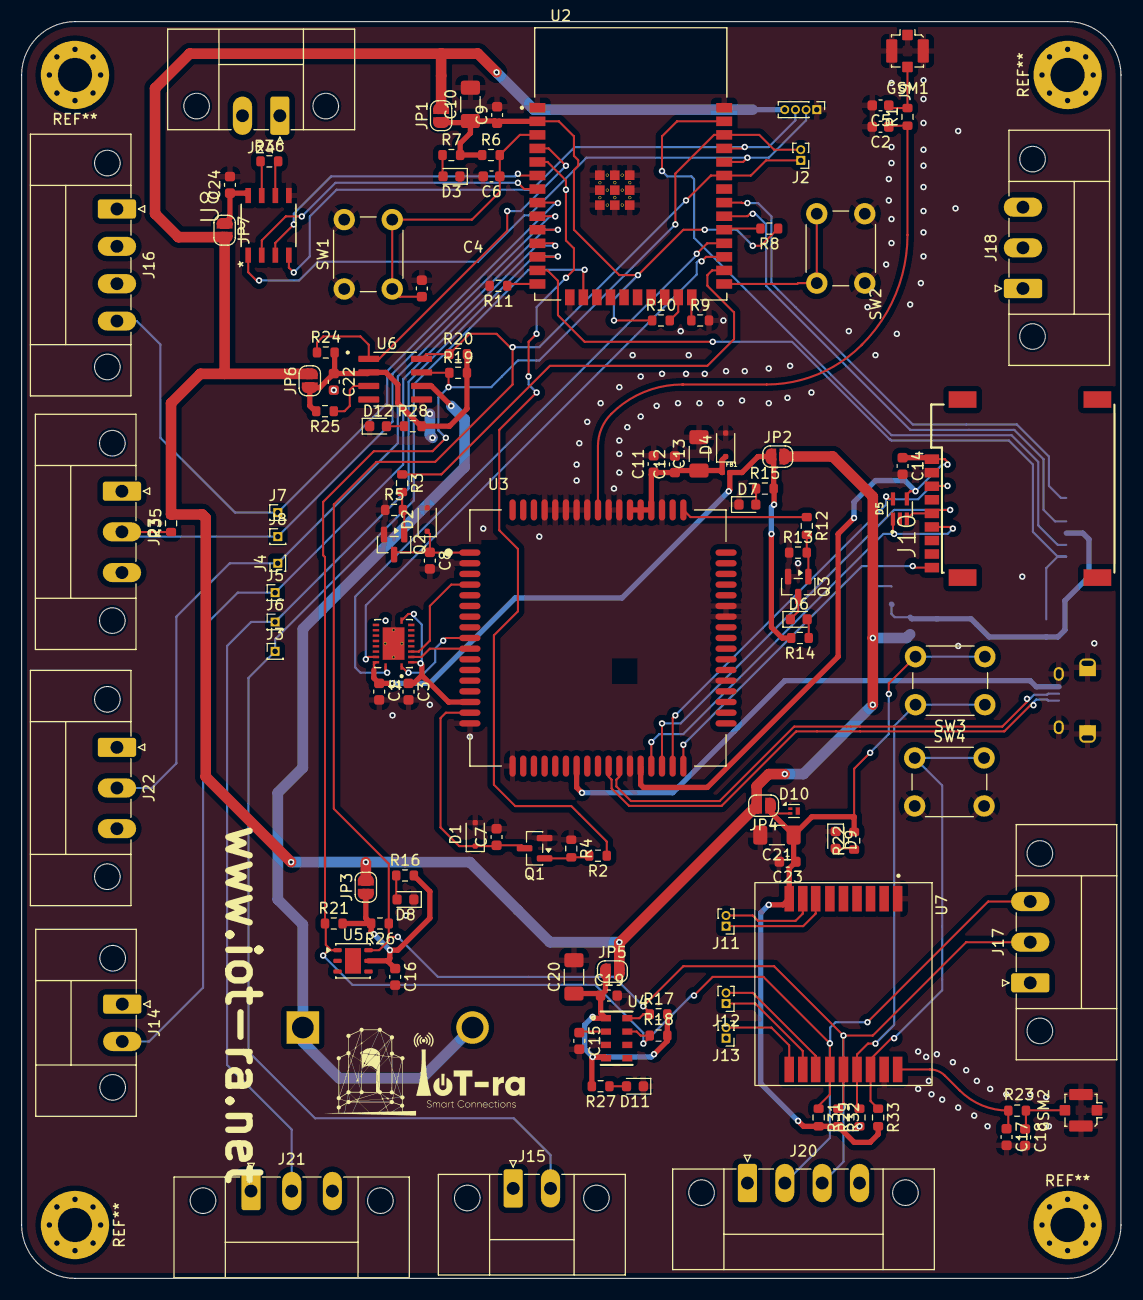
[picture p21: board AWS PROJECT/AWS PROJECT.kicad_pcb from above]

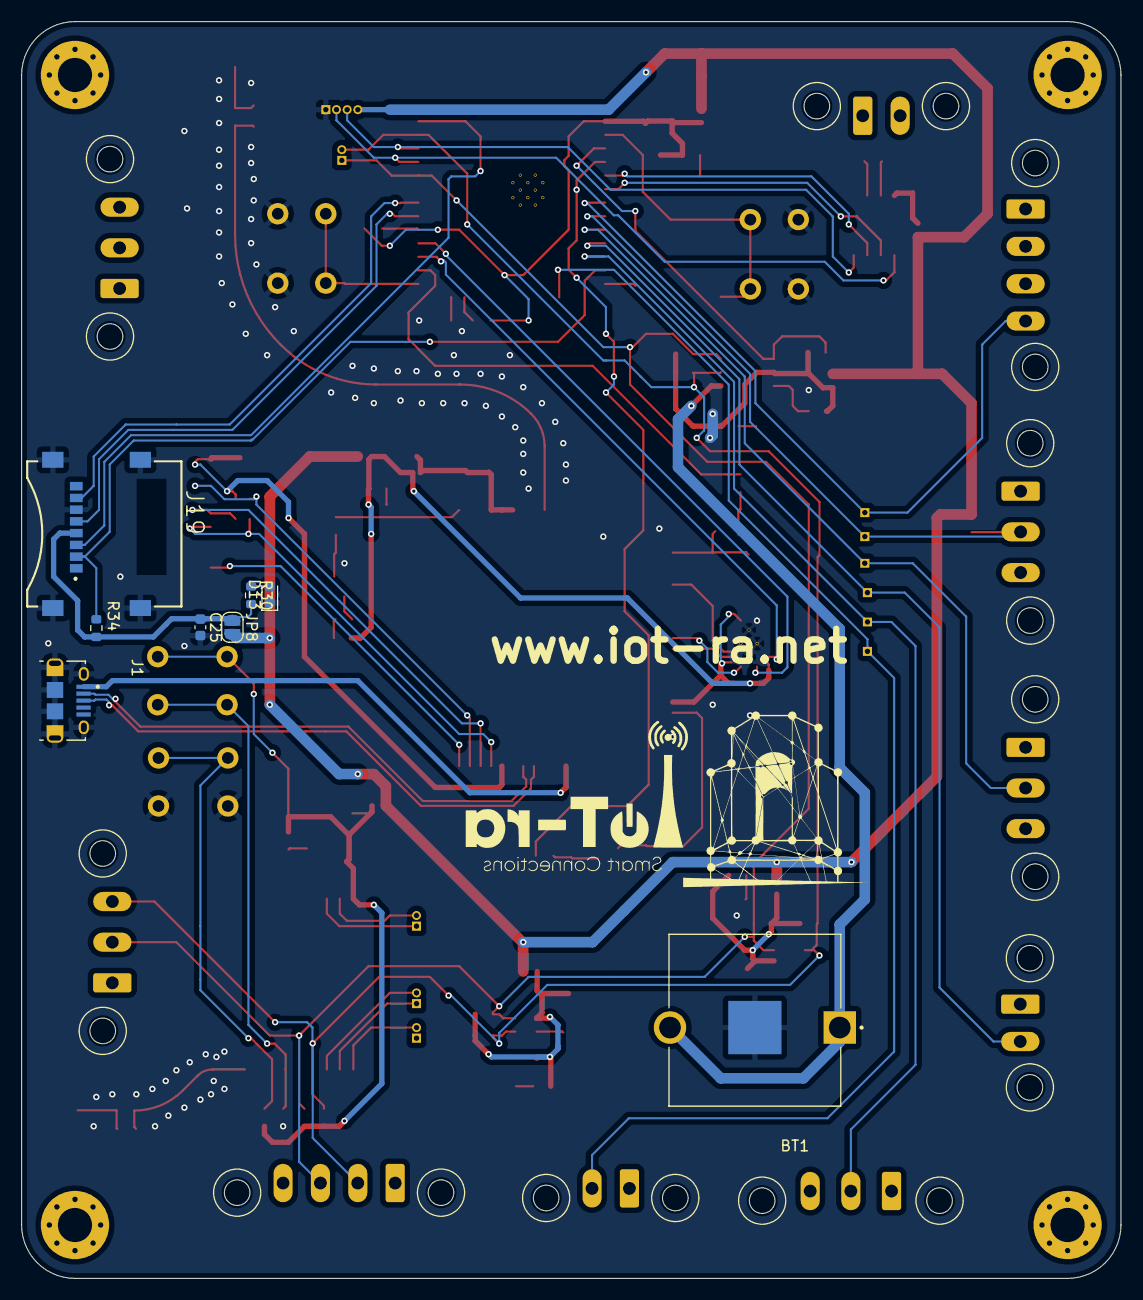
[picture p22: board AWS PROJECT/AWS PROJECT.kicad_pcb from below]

Board: 2 copper layers, 103.0 x 117.8 mm, 125 parts (8 on the bottom side), 81 nets.

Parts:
BT1: BHX1-1225-PC; BAT_BHX1-1225-PC
C1, C3, C4, C7, C8, C9, C11, C14, C15, C16, C19, C22, C23, C24: 0.1uF; C_0603_1608Metric
C2, C5, C17, C18: Cm; C_0603_1608Metric
C6, C12, C25: 1uF; C_0603_1608Metric
C10: 22uF; C_1206_3216Metric_Pad1.33x1.80mm_HandSolder
C13: 100uF; C_1206_3216Metric_Pad1.33x1.80mm_HandSolder
C20, C21: 10uF; C_1206_3216Metric_Pad1.33x1.80mm_HandSolder
D1, D2, D4: PESDHC3D3V3U; D_SOD-323F
D3, D6, D7, D8, D9, D11, D12, D13: NET_LED; D_0603_1608Metric
D5: ESDA6V1W5; SOT65P210X110-5N
D10: PESDHC2FD4V5B; Diodes_DFN1006-3
FB1: FerriteBead_Small; BEADC0603X33N
GSM1, GSM2: U.FL-R-SMT(10); U.FL_Molex_MCRF_73412-0110_Vertical
J1: 10118194-0001LF; AMPHENOL_10118194-0001LF
J2, J11, J12, J13: Conn_01x02_Pin; PinHeader_1x02_P1.00mm_Vertical
J3, J4, J5, J6, J7, J8: Conn_01x01_Pin; PinHeader_1x01_P1.00mm_Vertical
J9: Conn_01x04_Pin; PinHeader_1x04_P1.00mm_Vertical
J10: SIM7100-8-1-15-00-A_REVC; GCT_SIM7100-8-1-15-00-A_REVC
J14, J15: Conn_01x02_Pin; PhoenixContact_MC_1,5_2-GF-3.5_1x02_P3.50mm_Horizontal_Thre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
J16, J20: Conn_01x04_Pin; PhoenixContact_MC_1,5_4-GF-3.5_1x04_P3.50mm_Horizontal_Thre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
J17, J18, J21, J22, J23: Conn_01x03_Pin; PhoenixContact_MC_1,5_3-GF-3.81_1x03_P3.81mm_Horizontal_Thr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
J19: MEM2067-02-180-00-A_REVB; GCT_MEM2067-02-180-00-A_REVB
J24: Screw_Terminal_01x02; PhoenixContact_MC_1,5_2-GF-3.5_1x02_P3.50mm_Horizontal_Thre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
JP1, JP2, JP3, JP4, JP5, JP6, JP7, JP8: Jumper_2_Small_Open; SolderJumper-2_P1.3mm_Open_RoundedPad1.0x1.5mm
Q1, Q2, Q3: MMBT3904; SOT-23
R1, R23: 0R; R_0603_1608Metric
R2, R3, R4, R5, R12, R13, R17, R18, R19, R20, R21, R24, R25, R26, R31, R32, R35: 4.7k; R_0603_1608Metric
R6, R8, R9, R10, R11, R29, R33: 10k; R_0603_1608Metric
R7, R14, R15, R16, R22, R27, R28, R30, R34: 1k; R_0603_1608Metric
R36: 120; R_0603_1608Metric
SW1, SW2, SW3, SW4: SW_SPST; SW_PUSH_6mm
U1: TXB0108RGYR; IC_TXB0108RGYR
U2: ESP32-WROOM-32E__4MB_HIGH_TEMP_; XCVR_ESP32-WROOM-32E__4MB_HIGH_TEMP_
U3: SIM7000E; SIMCON_SIM7000E
U4: MPL3115A2; PSON125P300X500X120-8N
U5: DFN-6-1EP_3x3mm_P1mm_EP1.5x2.4mm
U6: DS3231MZ_TRL; SOIC127P600X175-8N
U7: Ai-Thinker RA-08H; RA-08H
U8: ST3485EBDR; SOIC127P600X175-8N

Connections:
3v3: J9.4, JP1.2 (B), JP2.2 (B), JP3.2 (B), JP4.2 (B), JP5.2 (B), JP6.2 (B), JP7.2 (B), JP8.2 (B), R35.2
/gate way/32khz: R24.1, U2.4 (SENSOR_VP), U6.1 (32KHZ)
/gate way/-rs485 en: U2.7 (IO35), U8.2 (~RE)
/gate way/D+: J1.3 (D+), U3.27 (USB_DP)
/gate way/D-: J1.2 (D-), U3.28 (USB_DM)
/gate way/DAVIS 7852: J7.1, J16.4, U2.8 (IO32)
/gate way/DS18B20: J8.1, J23.2, R35.1, U2.9 (IO33)
/gate way/ESP32 power in: C9.1, C10.1, JP1.1 (A), R6.1, R7.2, R8.1, R10.1, U2.2 (3V3)
/gate way/GSM_pw in: C1.1, FB1.2, JP2.1 (A), R14.2, R15.2, U1.19 (VCCB)
/gate way/I2C SCL: J2.1, J17.2, J20.3, R17.1, R20.1, R26.1, R32.1, U2.33 (IO21), U4.8 (SCL), U5.6 (SCL), U6.8 (SCL), U7.14 (IO14)
/gate way/I2C SDA: J2.2, J17.3, J20.2, R18.1, R19.1, R21.1, R31.1, U2.36 (IO22), U4.7 (SDL), U5.1 (SDA), U6.7 (SDA), U7.13 (IO15)
/gate way/INSPEED VORTEX: J5.1, J14.2, U2.11 (IO26)
/gate way/INSPEEED VANE: J6.1, J21.2, U2.12 (IO27)
/gate way/LORA ANT: C17.1, R23.1, U7.18 (ANT)
/gate way/LORA BOOT: R29.2, SW3.1 (A), U7.15 (IO2/BOOT)
/gate way/LORA RST: R33.1, SW4.1 (A), U7.16 (RST)
/gate way/MPL power input: C19.1, C20.1, JP5.1 (A), R17.2, R18.2, R27.2, U4.1 (VDD), U4.4 (VDDIO)
/gate way/RS485 power in: C24.1, JP7.1 (A), U8.8 (VCC)
/gate way/RTC INT: R25.1, U6.3 (~INT/SQW)
/gate way/RTC power input: C22.1, JP6.1 (A), R19.2, R20.2, R24.2, R25.2, R28.2, U6.2 (VCC)
/gate way/RX: U1.18 (B2), U2.27 (IO16)
/gate way/S1223: J3.1, J15.2, U2.16 (IO13)
/gate way/SD CS: J19.2 (CD/DAT3), R34.1, U2.13 (IO14)
/gate way/SD power in: C25.1, J19.4 (VDD), JP8.1 (A), R30.2, R34.2
/gate way/SHT25 power in: C16.1, JP3.1 (A), R16.2, R21.2, R26.2, U5.5 (VDD)
/gate way/SIM CLK: D5.3, J10.C3 (CLK), U3.32 (SIM_CLK)
/gate way/SIM DATA: D5.1, J10.C7 (IO), U3.31 (SIM_DATA)
/gate way/SIM DET: J10.CD, U3.34 (SIM_DET)
/gate way/SIM RST: D5.5, J10.C2 (RST), U3.33 (SIM_RST)
/gate way/SIM VDD: C14.1, D5.4, J10.C1 (VCC), U3.30 (SIM_VDD)
/gate way/TX: U1.20 (B1), U2.28 (IO17)
/gate way/VBUS: J1.1 (VCC), U3.24 (USB_VBUS)
/gate way/VDD_EXT: C3.1, U1.2 (VCCA), U1.10 (OE), U3.15 (VDD_EXT)
/gate way/VH400: J4.1, J22.2, U2.10 (IO25)
/gate way/VSPI-CLK: J19.5 (CLK), U2.30 (IO18)
/gate way/VSPI-MISO: J19.7 (DAT0), U2.31 (IO19)
/gate way/VSPI-MOSI: J19.3 (CMD), U2.37 (IO23)
/gate way/gsm power key: R3.1, U2.26 (IO4)
/gate way/gsm reset: R2.1, U2.5 (SENSOR_VN)
/gate way/gsm rx: U1.3 (A2), U3.10 (RXD)
/gate way/gsm tx: U1.1 (A1), U3.9 (TXD)
/gate way/lora power in: C21.1, C23.1, D10.2 (C), JP4.1 (A), R22.2, R31.2, R32.2, R33.2, SW3.2 (B), U7.9 (VCC)
/gate way/main ant: C2.1, R1.1, U3.60 (RF_ANT)
/gate way/netlight: R12.1, U3.52 (NETLIGHT)
/gate way/nreset: C7.1, D1.1, Q1.3 (C), U3.16 (~NRESET)
/gate way/pwkey: C8.1, D2.1, Q2.3 (C), U3.1 (~PWRKEY)
/gate way/ri: U1.4 (A3), U3.4 (RI)
/gate way/rs485 en: U2.6 (IO34), U8.3 (DE)
/gate way/rx: J9.2, U2.34 (RXD0), U8.1 (RO)
/gate way/strap2: R9.1, U2.24 (IO2)
/gate way/strap12: R11.1, U2.14 (IO12)
/gate way/strap15: R10.2, U2.23 (IO15)
/gate way/strap 5: R8.2, U2.29 (IO5)
/gate way/tx: J9.3, U2.35 (TXD0), U8.4 (DI)
GND: BT1.2, C1.2, C2.2, C3.2, C4.1, C5.2, C6.2, C7.2, C8.2, C9.2, C10.2, C11.2, C12.2, C13.2, C14.2, C15.2, C16.2, C17.2, C18.2, C19.2, C20.2, C21.2, C22.2, C23.2, C24.2, C25.2, D1.2, D2.2, D3.1 (K), D4.2, D5.2, D7.1 (K), D8.1 (K), D9.1 (K), D10.1 (A), D11.1 (K), D12.1 (K), D13.1 (K), GSM1.2, GSM2.2, J1.5 (GND), J1.SH1 (SHIELD), J1.SH2 (SHIELD), J1.SH3 (SHIELD), J1.SH4 (SHIELD), J1.SH5 (SHIELD), J1.SH6 (SHIELD), J9.1, J10.C5 (GND), J19.6 (VSS), J19.9 (SHIELD), J19.10 (SHIELD), J19.11 (SHIELD), J19.12 (SHIELD), Q1.2 (E), Q2.2 (E), Q3.2 (E), R4.1, R5.1, R9.2, R11.2, R13.1, R29.1, SW1.1 (A), SW2.2 (B), SW4.2 (B), U1.11 (GND), U1.21 (EXP), U1.21_1 (EXP), U1.21_2 (EXP), U1.21_3 (EXP), U1.21_4 (EXP), U2.1 (GND), U2.15 (GND), U2.38 (GND), U2.39_1 (GND), U2.39_2 (GND), U2.39_3 (GND), U2.39_4 (GND), U2.39_5 (GND), U2.39_6 (GND), U2.39_7 (GND), U2.39_8 (GND), U2.39_9 (GND), U3.2 (GND), U3.17 (GND), U3.18 (GND), U3.29 (GND), U3.39 (GND), U3.45 (GND), U3.46 (GND), U3.54 (GND), U3.58 (GND), U3.59 (GND), U3.61 (GND), U3.62 (GND), U3.63 (GND), U3.64 (GND), U3.65 (GND), U4.3 (GND), U5.2 (VSS/GND), U6.5 (GND), U7.1 (GND), U7.17 (GND), U8.5 (GND)
unnamed: C5.1, GSM1.1, R1.2
unnamed: C11.1, C12.1, C13.1, D4.1, FB1.1, U3.55 (VBAT), U3.56 (VBAT), U3.57 (VBAT)
unnamed: C18.1, GSM2.1, R23.2
unnamed: D3.2 (A), R7.1
unnamed: D6.2 (A), R14.1
unnamed: D6.1 (K), Q3.3 (C)
unnamed: D7.2 (A), R15.1
unnamed: D8.2 (A), R16.1
unnamed: D9.2 (A), R22.1
unnamed: D11.2 (A), R27.1
unnamed: D12.2 (A), R28.1
unnamed: D13.2 (A), R30.1
unnamed: J11.1, U7.7 (SWC/IO7)
unnamed: J11.2, U7.8 (SWD/IO6)
unnamed: J12.1, U7.11 (TXD/IO17)
unnamed: J12.2, U7.12 (RXD/IO16)
unnamed: J13.2, U7.10 (LPRXD/IO60)
unnamed: J24.1, R36.2, U8.6 (A)
unnamed: J24.2, R36.1, U8.7 (B)
unnamed: Q1.1 (B), R2.2, R4.2
unnamed: Q2.1 (B), R3.2, R5.2
unnamed: Q3.1 (B), R12.2, R13.2
unnamed: C4.2, C6.1, R6.2, SW1.2 (B), U2.3 (EN)
unnamed: SW2.1 (A), U2.25 (IO0)
unnamed: C15.1, U4.2 (CAP)
unnamed: BT1.1, BT1.1_1, U6.6 (VBAT)

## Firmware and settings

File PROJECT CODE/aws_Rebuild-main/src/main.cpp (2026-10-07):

#include "config.h"
#include "portal_html.h"
#include "calibration.h"
#include "serial_ui.h"

// ---------- Object Instances ----------
Adafruit_ADS1115      ads;
Adafruit_INA219      batterySensor(0x40);
Adafruit_INA219      solarSensor(0x41);
RTC_DS3231           rtc;
DHT                  dht(DHTPIN, DHTTYPE);
Preferences          preferences;

// ---------- DS18B20 Objects ----------
OneWire              oneWire(DS18B20_PIN);
DallasTemperature    ds18b20(&oneWire);
bool                 ds18b20Ok = false;

// ---------- BME280 (pressure) ----------
// Not fitted yet. Probed on every rail power-up, so the sensor starts working
// the moment it is plugged in - no reflash required.
Adafruit_BME280      bme;
bool                 bmeOk = false;

// ---------- Global Variables ----------
int sleepIntervalSec = 300;
String stationCode = "AWS-UG-001";
bool relayOn = false;

// ---------- Clock State ----------
bool rtcOk = false;
bool rtcTimeValid = false;
static bool ntpEverSynced = false;          // NTP succeeded at least once this boot
static unsigned long lastNtpSyncMs = 0;     // millis() of last success
static unsigned long lastNtpAttemptMs = 0;  // millis() of last attempt, success or not
DataRecord lastRecord;
bool haveLastRecord = false;
uint32_t nextCycleEpoch = 0;
int queueDepthCached = 0;
unsigned long nextCycleMillis = 0;

// ================== WIND & RAIN PULSE COUNTING ==================
// Pulses have to be counted whether the CPU is awake or in light sleep, and
// light sleep only supports LEVEL-triggered GPIO wake - not edges. So there are
// two ways into the counters:
//
//   awake  - the edge ISRs below
//   asleep - esp_light_sleep_start() returns on a LOW level and the wake
//            handler counts the pulse directly
//
// Both funnel through countWindPulse()/countRainPulse(), which share one
// debounce timestamp per channel. Without that shared timestamp a single reed
// closure is counted twice: once by the level wake, once by the edge ISR as the
// CPU resumes.

volatile uint32_t windPulseCount = 0;
volatile uint32_t rainPulseCount = 0;
static volatile uint32_t lastWindPulseUs = 0;
static volatile uint32_t lastRainPulseUs = 0;

// GPIO wakes where neither line was still low by the time we read it - i.e.
// pulses too short to attribute. Reported each interval so it stays visible.
static volatile uint32_t ambiguousWakes = 0;

// Gust = the highest 3 s average within the interval. Tracked as a running
// "best" bucket. Deliberately integer-only: doing float maths inside an IRAM
// ISR means relying on FPU state being saved, which it is not by default.
static volatile uint32_t gustBucketStartUs = 0;
static volatile uint32_t gustBucketCount   = 0;
static volatile uint32_t gustBestCount     = 0;
static volatile uint32_t gustBestSpanUs    = 1;   // 1, not 0, so the first compare works

// When the current interval started. Seeded in setup() at the moment the
// interrupts are armed, so the first burst divides by the time counting has
// actually been running rather than by an assumed full interval.
static uint32_t      lastSnapshotEpoch  = 0;
static unsigned long lastSnapshotMillis = 0;

// Interval results, refreshed by snapshotPulseCounters().
float windSpeed_MPH = 0.0;
float windSpeed_MS  = 0.0;
float windGust_MS   = 0.0;
float rain_mm       = 0.0;   // mm accumulated in the current interval, zeroed each snapshot
float lastIntervalSec = 0.0;   // what windSpeed_MS and rain_mm actually average over

void IRAM_ATTR countWindPulse() {
  uint32_t now = micros();
  if ((uint32_t)(now - lastWindPulseUs) < WIND_DEBOUNCE_US) return;
  lastWindPulseUs = now;
  windPulseCount++;

  // Close the gust bucket once it has run its full width and keep it if it beat
  // the best so far. Comparing count/span as a cross-multiply avoids a divide.
  uint32_t span = now - gustBucketStartUs;
  if (span >= GUST_WINDOW_US) {
    if ((uint64_t)gustBucketCount * (uint64_t)gustBestSpanUs >
        (uint64_t)gustBestCount * (uint64_t)span) {
      gustBestCount  = gustBucketCount;
      gustBestSpanUs = span;
    }
    gustBucketStartUs = now;
    gustBucketCount   = 0;
  }
  gustBucketCount++;
}

void IRAM_ATTR countRainPulse() {
  uint32_t now = micros();
  if ((uint32_t)(now - lastRainPulseUs) < DEBOUNCE_US) return;
  lastRainPulseUs = now;
  rainPulseCount++;
}

void IRAM_ATTR windISR() { countWindPulse(); }
void IRAM_ATTR rainISR() { countRainPulse(); }

// ---------- Clock reference ----------
// The DS3231 sits on the gated sensor rail, so it is only readable during a
// burst. Between bursts the last good reading is carried forward on millis(),
// which keeps advancing across light sleep.
static uint32_t      clockRefEpoch  = 0;
static unsigned long clockRefMillis = 0;

// The DS3231 holds EAT, so this is not a true UTC epoch - but every use here is
// a difference between two of them, which is unaffected. Returns 0 only when
// the time is not known at all.
uint32_t currentEpoch() {
  if (rtcOk && relayOn) {
    DateTime now = rtc.now();
    if (now.isValid() && now.year() >= RTC_MIN_VALID_YEAR) {
      clockRefEpoch  = now.unixtime();
      clockRefMillis = millis();
      rtcTimeValid   = true;
      return clockRefEpoch;
    }
    // The rail is up and it still did not answer sensibly, so the clock really
    // is unset. Only latch invalid here: a failed read with the rail down means
    // nothing at all, and latching on it strands every later record at 1970.
    rtcTimeValid = false;
  }

  if (clockRefEpoch > 0) {
    return clockRefEpoch + (uint32_t)((millis() - clockRefMillis) / 1000UL);
  }
  return 0;
}

// ---------- Close out the interval ----------
// Called once at the top of each duty cycle, so every pulse is attributed to
// exactly one interval and nothing is double counted.
void snapshotPulseCounters() {
  noInterrupts();
  uint32_t windPulses = windPulseCount;  windPulseCount = 0;
  uint32_t rainTips   = rainPulseCount;  rainPulseCount = 0;
  uint32_t bestCount  = gustBestCount;
  uint32_t bestSpan   = gustBestSpanUs;
  gustBestCount     = 0;
  gustBestSpanUs    = 1;
  gustBucketCount   = 0;
  gustBucketStartUs = micros();
  interrupts();

  // Elapsed time comes from the RTC, not micros(), which wraps every ~71 min -
  // uncomfortably close to the 60 min maximum interval. millis() is the
  // fallback when the clock is unknown; it advances across light sleep too.
  uint32_t nowEpoch = currentEpoch();
  float elapsed;
  if (nowEpoch > 0 && lastSnapshotEpoch > 0 && nowEpoch > lastSnapshotEpoch) {
    elapsed = (float)(nowEpoch - lastSnapshotEpoch);
  } else if (lastSnapshotMillis > 0) {
    elapsed = (float)(millis() - lastSnapshotMillis) / 1000.0f;
  } else {
    elapsed = (float)sleepIntervalSec;
  }
  lastSnapshotEpoch  = nowEpoch;      // 0 is fine - the millis path covers it
  lastSnapshotMillis = millis();
  if (elapsed < 1.0f) elapsed = 1.0f;

  float hz = (float)windPulses / elapsed;
  windSpeed_MPH = hz * WIND_MPH_PER_HZ;
  windSpeed_MS  = hz * WIND_MS_PER_HZ;

  float gustHz = (bestSpan > 0)
                 ? ((float)bestCount * 1000000.0f / (float)bestSpan)
                 : 0.0f;
  windGust_MS = gustHz * WIND_MS_PER_HZ;
  // With few pulses no bucket ever closes, which would report a gust below the
  // interval mean. The gust can never be less than the average.
  if (windGust_MS < windSpeed_MS) windGust_MS = windSpeed_MS;

  rain_mm = (float)rainTips * MM_PER_TIP;
  lastIntervalSec = elapsed;

  uint32_t missed = ambiguousWakes;
  ambiguousWakes = 0;
  if (missed > 0) {
    logWarn("%lu wake(s) not attributable to a pin - pulses may be undercounted.",
                  (unsigned long)missed);
  }

  logStep("wind %lu pulses / %.0f s -> %.2f m/s avg, %.2f m/s gust | rain %lu tips -> %.1f mm",
                (unsigned long)windPulses, elapsed, windSpeed_MS, windGust_MS,
                (unsigned long)rainTips, rain_mm);
}

// ================== LIGHT SLEEP ==================

// Light-sleep wake is level-triggered, so re-arming while the contact is still
// closed wakes instantly and spins at full power. Bounded so a stuck-closed
// reed shows up as a fault instead of a silent flat battery.
static bool waitForReedRelease(uint8_t pin) {
  uint32_t start = millis();
  while (digitalRead(pin) == LOW) {
    if ((millis() - start) > REED_RELEASE_MS) return false;
    delay(1);
  }
  return true;
}

static void reportStuckReed(const char *which) {
  // Rate limited, and Serial-only: the SD rail is powered down during sleep.
  static uint32_t lastReportMs = 0;
  if ((millis() - lastReportMs) < 60000UL) return;
  lastReportMs = millis();
  logWarn("%s reed still closed after %d ms - check for a stuck contact.",
                which, REED_RELEASE_MS);
}

void sleepUntilNextEventOrDeadline() {
  // How long we are allowed to stay down. Deliberately millis()-based rather
  // than reading the RTC: if the DS3231 shares the gated rail it is
  // unreachable right now, and esp_timer accounts for light sleep so millis()
  // keeps advancing. The deadline is re-derived from the RTC at the top of
  // every burst, so drift cannot accumulate across cycles.
  long msLeft = (long)(nextCycleMillis - millis());
  if (msLeft <= 0) return;                          // burst is due

  long remaining = msLeft / 1000;
  if (remaining < 1)                remaining = 1;
  if (remaining > SLEEP_CHUNK_SEC)  remaining = SLEEP_CHUNK_SEC;

  // The radio must be down: light sleep with WiFi up either draws far more or
  // is rejected outright.
  if (WiFi.getMode() != WIFI_OFF) WiFi.mode(WIFI_OFF);

  // Hand the pins from the Arduino edge ISRs to the level-triggered wake, then
  // hand them back afterwards. The two share the GPIO interrupt-type register,
  // and the driver source is not shipped with the core, so rather than assume
  // how gpio_wakeup_enable() treats an already-attached edge interrupt, this
  // makes the ownership explicit in both directions.
  detachInterrupt(digitalPinToInterrupt(WIND_PIN));
  detachInterrupt(digitalPinToInterrupt(RAIN_PIN));

  gpio_wakeup_enable((gpio_num_t)WIND_PIN, GPIO_INTR_LOW_LEVEL);
  gpio_wakeup_enable((gpio_num_t)RAIN_PIN, GPIO_INTR_LOW_LEVEL);
  esp_sleep_enable_gpio_wakeup();
  esp_sleep_enable_timer_wakeup((uint64_t)remaining * 1000000ULL);

  esp_err_t err = esp_light_sleep_start();

  if (err == ESP_OK && esp_sleep_get_wakeup_cause() == ESP_SLEEP_WAKEUP_GPIO) {
    // Classic ESP32 has no esp_sleep_get_gpio_wakeup_status() - that API sits
    // behind SOC_GPIO_SUPPORT_DEEPSLEEP_WAKEUP, which only the S2/S3/C3 set.
    // The wake was level-triggered, so whichever line is still low is the one
    // that woke us. A closure shorter than the wake latency can slip through;
    // ambiguousWakes counts those so the loss is measurable rather than silent.
    // Sample both lines first: the contact that woke us may reopen within
    // milliseconds, and anything read later is already too late.
    bool windLow = (digitalRead(WIND_PIN) == LOW);
    bool rainLow = (digitalRead(RAIN_PIN) == LOW);

    // Give the pins back to the edge ISRs BEFORE the release waits below.
    // Those waits can run for REED_RELEASE_MS each, and with the ISRs still
    // detached a tip on the other channel during that window would vanish.
    // Re-arming here cannot double count: the line is already low, so there is
    // no falling edge to fire on, and the shared debounce covers the rest.
    gpio_wakeup_disable((gpio_num_t)WIND_PIN);
    gpio_wakeup_disable((gpio_num_t)RAIN_PIN);
    attachInterrupt(digitalPinToInterrupt(WIND_PIN), windISR, FALLING);
    attachInterrupt(digitalPinToInterrupt(RAIN_PIN), rainISR, FALLING);

    if (windLow) {
      countWindPulse();
      if (!waitForReedRelease(WIND_PIN)) reportStuckReed("Wind");
    }
    if (rainLow) {
      countRainPulse();
      if (!waitForReedRelease(RAIN_PIN)) reportStuckReed("Rain");
    }
    if (!windLow && !rainLow) ambiguousWakes++;
  } else {
    // Timer wake, or sleep was rejected - nothing to attribute, just restore.
    gpio_wakeup_disable((gpio_num_t)WIND_PIN);
    gpio_wakeup_disable((gpio_num_t)RAIN_PIN);
    attachInterrupt(digitalPinToInterrupt(WIND_PIN), windISR, FALLING);
    attachInterrupt(digitalPinToInterrupt(RAIN_PIN), rainISR, FALLING);
  }
}

// ---------- Config Load / Save ----------
void loadConfig() {
  preferences.begin("weather", false);
  // getInt() reports a missing key at log_v, but getString() uses log_e even
  // when a default is supplied - so probe with isKey() to keep a fresh NVS
  // from printing errors that are not errors.
  sleepIntervalSec = preferences.getInt("sleepInt", 300);
  stationCode = preferences.isKey("station")
                ? preferences.getString("station")
                : String("AWS-UG-001");
  preferences.end();
  logOk("Config loaded: interval %d s, station %s", sleepIntervalSec, stationCode.c_str());
}

void saveConfig(int newInterval, const String &newStation) {
  preferences.begin("weather", false);
  if (newInterval > 0) preferences.putInt("sleepInt", newInterval);
  if (newStation.length() > 0) preferences.putString("station", newStation);
  preferences.end();
  if (newInterval > 0) sleepIntervalSec = newInterval;
  if (newStation.length() > 0) stationCode = newStation;
  logOk("Config saved: interval %d s, station %s", sleepIntervalSec, stationCode.c_str());
}
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
void loop() {
  // ============================================
  // PHASE 1: MEASURE (sensor rail up, radio still down)
  // ============================================
  sensorRailUp();             // power up, remount SD, re-init the I2C devices

  // Close out the interval: snapshot and reset the wind/rain counters, then
  // derive average wind, gust and accumulated rainfall from them.
  snapshotPulseCounters();

  // Fix the next burst time now, while the rail is up and the RTC is
  // reachable. Re-deriving it here every cycle means millis() drift over one
  // interval never accumulates across cycles.
  nextCycleMillis = millis() + (unsigned long)sleepIntervalSec * 1000UL;
  uint32_t burstEpoch = currentEpoch();
  nextCycleEpoch = (burstEpoch > 0) ? burstEpoch + (uint32_t)sleepIntervalSec : 0;

  DataRecord rec;
  readSensors(rec);
  lastRecord     = rec;       // the config portal reads this
  haveLastRecord = true;
  printSensorValues(rec);

  // The archive is permanent and takes everything - even an unstamped record,
  // because the readings are still real and the sentinel timestamp makes the
  // gap obvious. The upload queue only takes what the server can accept.
  archiveRecord(rec);
  if (rec.timestamp == TIMESTAMP_INVALID) {
    logError("Clock not set - record archived but not queued for upload.");
  } else {
    enqueueRecord(rec);
  }
  logOk("Record written to SD.");

#if SD_INDEPENDENT_POWER
  sensorRailDown();
  logStep("Sensor rail OFF.");
#endif

  // ============================================
  // PHASE 2: TRANSMIT
  // ============================================
  // The queue drain covers the record just written as well as any backlog, so
  // there is no separate "send the current reading" step to duplicate it.
  if (connectWiFi()) {
    maybeResyncRTC();         // opportunistic: first chance, then once a day
    if (!processPendingQueue()) {
      logWarn("Queue not fully drained - the rest waits for next cycle.");
    }
  } else {
    logError("No WiFi this cycle - the queue is left untouched.");
  }

  sensorRailDown();
  logStep("Sensor rail OFF.");

  // ============================================
  // PHASE 3: CONFIG PORTAL
  // ============================================
  runConfigPortal();

  // ============================================
  // PHASE 4: LIGHT SLEEP (still counting pulses)
  // ============================================
  // Default state from here until the next burst. The CPU is clock-gated but
  // RAM and peripherals survive, and a wind or rain pulse wakes it briefly to
  // count before going straight back down.
  //
  // The deadline was fixed at the top of this burst, while the rail was still
  // up. Nothing below reads the RTC, so this works whether or not the DS3231
  // shares the gated rail.
  long sleepLeft = (long)(nextCycleMillis - millis()) / 1000;
  if (sleepLeft < 0) sleepLeft = 0;
  logStep("Sleeping %ld s until the next burst (wind/rain still counted)...",
                sleepLeft);
  Serial.flush();   // the UART has to drain before the clock stops

  while ((long)(millis() - nextCycleMillis) < 0) {
    sleepUntilNextEventOrDeadline();
  }

  logStep("Sleep period finished.");
  Serial.println();
}

// ================== SENSOR READING ==================
void readSensors(DataRecord &rec) {
  rec.timestamp = getTimestamp();

  // ---- Wind & rain ----
  // Already computed by snapshotPulseCounters() at the top of the duty cycle;
  // reading them here would reset the counters a second time.
  rec.windMPH      = windSpeed_MPH;
  rec.windMS       = windSpeed_MS;
  rec.windGustMS   = windGust_MS;
  rec.rainInterval_mm = rain_mm;

  // ---- DHT22 (Air Temperature & Humidity) ----
  // Retry rather than discard a whole interval's temperature on one bad
  // checksum. The spacing also covers the sensor's power-up settling time,
  // which the rail power-cycle makes relevant on every burst.
  float t = NAN, h = NAN;
  int attempt = 1;
  for (; attempt <= DHT_READ_ATTEMPTS; attempt++) {
    t = dht.readTemperature();
    h = dht.readHumidity();
    if (!isnan(t) && !isnan(h)) break;
    if (attempt < DHT_READ_ATTEMPTS) delay(DHT_RETRY_DELAY_MS);
  }

  if (isnan(t) || isnan(h)) {
    logError("DHT22 read failed after " + String(DHT_READ_ATTEMPTS) +
             " attempts - check VCC (3.3-6 V), the data pull-up and the pin.");
    rec.temperature = NAN;      // NAN travels all the way to a NULL column
    rec.humidity    = NAN;
  } else {
    if (attempt > 1) logWarn("DHT22 needed %d attempts.", attempt);
    rec.temperature = t;
    rec.humidity    = h;
  }

  // ---- BME280 (station pressure) ----
  // Absent for now, so this stays NAN and the column stays NULL.
  if (bmeOk && bme.takeForcedMeasurement()) {
    float pa = bme.readPressure();                 // library returns pascals
    rec.pressure = isnan(pa) ? NAN : (pa / 100.0f);  // hPa
  } else {
    rec.pressure = NAN;
  }

  // ---- DS18B20 (Battery Temperature) ----
  if (ds18b20Ok) {
    ds18b20.requestTemperatures();
    float battTemp = ds18b20.getTempCByIndex(0);
    if (battTemp != DEVICE_DISCONNECTED_C) {
      rec.batteryTemp = battTemp;
    } else {
      logError("DS18B20 read failed (disconnected).");
      rec.batteryTemp = NAN;
      ds18b20Ok = false;
    }
  } else {
    rec.batteryTemp = NAN;
  }

  // ---- ADS1115 ----
  for (int i = 0; i < 4; i++) {
    int16_t raw = ads.readADC_SingleEnded(i);
    float v = ads.computeVolts(raw);
    switch (i) {
      case 0: rec.adc0 = v; break;
      case 1: rec.adc1 = v; break;
      case 2: rec.adc2 = v; break;
      case 3: rec.adc3 = v; break;
    }
  }

  // ---- INA219 Solar ----
  float sV = solarSensor.getBusVoltage_V();
  float sA = solarSensor.getCurrent_mA();
  if (isnan(sV) || isnan(sA)) {
    logError("INA219 Solar read failed.");
    rec.solarVoltage = NAN;     // 0.0 would read as a genuine measurement
    rec.solarCurrent_mA = NAN;
  } else {
    rec.solarVoltage = sV;
    rec.solarCurrent_mA = sA;
  }

  // ---- INA219 Battery ----
  float bV = batterySensor.getBusVoltage_V();
  float bA = batterySensor.getCurrent_mA();
  if (isnan(bV) || isnan(bA)) {
    logError("INA219 Battery read failed.");
    rec.batteryVoltage = NAN;
    rec.batteryCurrent_mA = NAN;
  } else {
    rec.batteryVoltage = bV;
    rec.batteryCurrent_mA = bA;
  }

  rec.intervalSec = (uint32_t)(lastIntervalSec + 0.5f);
  rec.sentMask    = 0;
  rec.retries     = 0;
}


// ================== CLOCK ==================
// Everything here works in East Africa Time (UTC+3). The DS3231 stores EAT
// directly, so SD rows and API payloads need no conversion.

static void formatDateTime(char *buf, size_t len,
                           int y, int mo, int d, int h, int mi, int s) {
  snprintf(buf, len, "%04d-%02d-%02d %02d:%02d:%02d", y, mo, d, h, mi, s);
}

// ---------- Timestamp ----------
// Returns TIMESTAMP_INVALID rather than a plausible-looking lie when the clock
// was never set - a wrong timestamp is worse than an obviously missing one.
String getTimestamp() {
  char buf[20];

  // currentEpoch() reads the DS3231 when its rail is up and carries the last
  // good reading forward on millis() when it is not.
  uint32_t e = currentEpoch();
  if (e > 0) {
    DateTime t(e);
    formatDateTime(buf, sizeof(buf), t.year(), t.month(), t.day(),
                   t.hour(), t.minute(), t.second());
    return String(buf);
  }

  // Fallback: the ESP32's own clock. Only trustworthy once NTP has answered
  // this boot, and it does not survive a power cut - hence the RTC.
  if (ntpEverSynced) {
    struct tm t;
    if (getLocalTime(&t, 0) && (t.tm_year + 1900) >= RTC_MIN_VALID_YEAR) {
      formatDateTime(buf, sizeof(buf), t.tm_year + 1900, t.tm_mon + 1, t.tm_mday,
                     t.tm_hour, t.tm_min, t.tm_sec);
      return String(buf);
    }
  }

  return String(TIMESTAMP_INVALID);
}

// ---------- Is the RTC holding a believable time? ----------
bool refreshRtcValidity() {
  if (!rtcOk || !relayOn) {
    // Nothing to test with the rail down - leave the previous verdict alone.
    return rtcTimeValid;
  }
  DateTime now = rtc.now();
  rtcTimeValid = now.isValid() && now.year() >= RTC_MIN_VALID_YEAR;
  if (rtcTimeValid) {
    clockRefEpoch  = now.unixtime();
    clockRefMillis = millis();
  }
  return rtcTimeValid;
}
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

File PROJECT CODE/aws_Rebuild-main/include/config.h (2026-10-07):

#ifndef CONFIG_H
#define CONFIG_H

// ========== Libraries ==========
#include <Arduino.h>
#include <Wire.h>
#include <Adafruit_ADS1X15.h>
#include <Adafruit_INA219.h>
#include <RTClib.h>
#include <DHT.h>
#include <SPI.h>
#include <SD.h>
#include <WiFi.h>
#include <HTTPClient.h>
#include <WiFiManager.h>
#include <Preferences.h>
#include <ArduinoJson.h>
#include <vector>
#include <OneWire.h>
#include <DallasTemperature.h>
#include <Adafruit_BME280.h>
#include <time.h>
#include <WebServer.h>
#include <DNSServer.h>
#include <esp_sleep.h>
#include <driver/gpio.h>

// ========== WiFi Credentials (FALLBACK - used only if no saved credentials) ==========
#define WIFI_SSID_FALLBACK     "AWS_MIFI"
#define WIFI_PASSWORD_FALLBACK "A2208554"
#define PORTAL_TIMEOUT         200   // seconds the config portal stays open
#define PORTAL_AP_SSID         "AWS-Conf"   // same SSID for our portal and WiFiManager

// ========== Pin Definitions ==========
#define RELAY_PIN       13
#define RELAY_ACTIVE    HIGH
#define I2C_SDA         21
#define I2C_SCL         22
#define WIND_PIN        27
#define RAIN_PIN        26
#define DHTPIN          25
#define DS18B20_PIN     32

#define SD_CS           5
#define SD_MOSI         23
#define SD_MISO         19
#define SD_SCK          18

// ========== Sensor Constants ==========
#define DHTTYPE         DHT22

// The AM2302 needs ~1 s after power-up before its first reading is valid, and
// returns a bad checksum now and then even when healthy. It will not produce a
// new sample faster than every 2 s, so retries have to be spaced accordingly.
#define DHT_READ_ATTEMPTS   3
#define DHT_RETRY_DELAY_MS  2200

// BME280 - not fitted yet. Detected on the bus at power-up, so plugging it in
// starts producing pressure with no reflash. Sends STATION pressure; mean
// sea-level pressure is derived server-side from the station altitude.
#define BME280_ADDR_A   0x76
#define BME280_ADDR_B   0x77
#define MM_PER_TIP      0.2
#define DEBOUNCE_US     100000      // 100 ms

// ========== Pulse Counting ==========
#define WIND_DEBOUNCE_US   5000UL      // 5 ms; at 30 Hz max the period is 33 ms
#define GUST_WINDOW_US     3000000UL   // 3 s - the standard gust averaging window
#define WIND_MPH_PER_HZ    1.5f
#define WIND_MS_PER_HZ     0.67f
#define REED_RELEASE_MS    50          // bounded wait for a reed contact to reopen

// ========== Light Sleep ==========
#define SLEEP_CHUNK_SEC    60          // wake at least this often to re-check the RTC

// ========== Time / RTC ==========
// The DS3231 holds LOCAL time: East Africa Time (UTC+3, no DST).
// SD logs and API payloads therefore all carry EAT.
#define TZ_OFFSET_SEC          (3 * 3600)
#define NTP_SERVER_1           "pool.ntp.org"
#define NTP_SERVER_2           "time.google.com"
#define NTP_SERVER_3           "time.nist.gov"
#define NTP_SYNC_TIMEOUT_MS    20000UL   // 10 s was tight when DNS is slow
#define NTP_RESYNC_INTERVAL_MS (24UL * 60UL * 60UL * 1000UL)   // re-sync daily
#define NTP_RETRY_INTERVAL_MS  (30UL * 60UL * 1000UL)          // floor between failed attempts
#define RTC_MIN_VALID_YEAR     2025   // older than this means the clock was never set
#define TIMESTAMP_INVALID      "1970-01-01 00:00:00"

// ========== Config Limits ==========
#define SLEEP_MIN_SEC          60
#define SLEEP_MAX_SEC          3600
#define STATION_CODE_MAXLEN    20

// ========== Server Endpoints ==========
#define BASE_URL        "https://api.wimea-ict.net/api/ingest/"
#define WEATHER_URL     BASE_URL "weather/"
#define VOLTAGE_URL     BASE_URL "voltage/"
#define CURRENT_URL     BASE_URL "current/"

// ========== SD Files ==========
// datalog.txt is the permanent archive - append only, never rewritten.
// queue.txt is the upload buffer - records leave it only once delivered.
// rejected.txt holds what the server permanently refused, so one bad record
// can never block the queue behind it.
#define SD_DATA_FILE     "/datalog.txt"
#define SD_QUEUE_FILE    "/queue.txt"
#define SD_QUEUE_TMP     "/queue.tmp"
#define SD_REJECTED_FILE "/rejected.txt"
#define SD_ERROR_FILE    "/error.log"

#define SD_CSV_HEADER "Timestamp,WindMPH,WindMS,WindGust_MS,Rain_mm,Temp_C,Humidity%,Pressure_hPa,BatteryTemp_C,Solar_V,Solar_mA,Batt_V,Batt_mA,ADC0,ADC1,ADC2,ADC3,Interval_s"

// Field counts for the CSV record format. Queue lines carry a format tag in
// front and two extra columns behind (delivery mask + retry count) that the
// archive does not need.
//
// The tag exists because field counts alone are not enough: when the record
// format gained columns, old queue lines still fell inside the accepted count
// range and were parsed with the new indices, shifting every field. Bump the
// tag whenever the layout changes and stale lines are rejected outright.
#define QUEUE_FORMAT_TAG  "QV3"
#define REC_FIELDS_BASE   18
#define REC_FIELDS_QUEUE  21
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

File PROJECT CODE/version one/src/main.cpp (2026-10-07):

#include <Arduino.h>
#include <Wire.h>
#include "WIFI_CONNECTION.h" // Even if unused, keeping your include
#include "DHT22.h"
#include "AIR_PRESSURE.h"
#include "LIGHT_SENSOR.h"
#include "SOILMOISTURE.h"
#include "RTC.h"
#include "GSM.h"
#include "DAVIS.h"
#include "WINDSPEED.h"
#include "WIND_DIRECTION.h"
#include "POWER_MONITORING.h"
#include "DataLogger.h"   // The new file handler class
#include "SensorData.h"   // The data struct

// Objects
// (Assumed your sensor constructors are correct as per your snippet)
DHTSensor dhtsensor;
AirPressure airpressure;
LightSensor lightsensor;
Soilmoisture soilmoisture;
Rtc rtc1;
Davis davisrain;
WindSpeedSensor windspeedsensor;
WindDirectionSensor winddirectionsensor;
PowerMonitoring powermonitoring;

GSM simmodule;
DataLogger dataLogger(4); // CS pin 4 for SD card

// Timer variables
unsigned long lastUploadTime = 0;
const long uploadInterval = 15000; // 15 seconds

void setup() {
    Serial.begin(9600);
    
    // 1. Initialize RTC
    rtc1.setupRTC();
    // (Optional: sync NTP if Wifi available, code omitted for brevity)

    // 2. Initialize Sensors
    // Note: Add logic inside your specific sensor setup() functions 
    // to handle missing hardware gracefully, or we handle it in loop.
    dhtsensor.getsensor(); // Assuming this is setup
    airpressure.sensor_setup();
    davisrain.setupRainGauge();
    windspeedsensor.setupSensor();
    winddirectionsensor.setupSensor();
    lightsensor.setupSensor();
    soilmoisture.setupSensor();
    powermonitoring.begin(21, 22);

    // 3. Initialize SD and GSM
    dataLogger.begin();
    simmodule.setupGSM(); // Includes GPRS setup
}

void loop() {
    SensorData currentData;

    // --- READ SENSORS (With Error Checking) ---

    // 1. Air Pressure / BME280
    // If your library returns NAN or 0 on failure, we sanitize it here.
    float p = airpressure.readPressure();
    currentData.airPressure = isnan(p) ? 0.0 : p;
    
    float alt = airpressure.readAltitude(1013.25);
    currentData.altitude = isnan(alt) ? 0.0 : alt;

    float t = airpressure.readTemperature(); // Using BME temp
    currentData.temperature = isnan(t) ? 0.0 : t;
    
    float h = airpressure.readHumidity();
    currentData.humidity = isnan(h) ? 0.0 : h;

    // 2. Power Monitoring
    if (powermonitoring.readData()) {
        VoltageData v = powermonitoring.getData();
        currentData.volt_3v3 = v.v1;
        currentData.volt_5v = v.v2;
        currentData.volt_batt = v.v3;
        currentData.volt_solar = v.v4;
        currentData.volt_dc = v.v5;
    } else {
        // Init to 0 if fails
        currentData.volt_3v3 = 0.0;
        currentData.volt_5v = 0.0;
        currentData.volt_batt = 0.0;
        currentData.volt_solar = 0.0;
        currentData.volt_dc = 0.0;
    }

    // 3. Other Sensors (Add basic checks if your libraries support it)
    currentData.lightLevel = lightsensor.readLightLevel(); // Ensure library returns 0 on fail
    currentData.soilMoisture = soilmoisture.readSoilMoisture();
    currentData.rainCount = davisrain.readRainGauge();
    currentData.windSpeed = windspeedsensor.readWindSpeedKPH();
    currentData.windDirection = winddirectionsensor.readWindDirectionDeg();

    // --- LOGGING ---

    // Get current time string
    String timeStr = String(rtc1.getDateTime().c_str());

    // Save to SD (DataLogger class handles formatting and error checking)
    dataLogger.logSensorData(timeStr, currentData);

    // --- UPLOAD ---
    
    if (millis() - lastUploadTime >= uploadInterval) {
        lastUploadTime = millis();
        
        Serial.println("Triggering Upload Sequence...");
        
        // This function retrieves the last logged line, 
        // deconstructs it, and sends it to the GSM module
        dataLogger.uploadLastDataToThingspeak(simmodule);
    }
    
    delay(1000); // 1 sec loop delay
}

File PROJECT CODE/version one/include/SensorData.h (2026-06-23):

<<<<<<< HEAD
#ifndef SENSOR_DATA_H
#define SENSOR_DATA_H

struct SensorData {
    float airPressure = 0.0;
    float altitude = 0.0;
    float temperature = 0.0; // From DHT or BME
    float humidity = 0.0;
    float lightLevel = 0.0;
    float soilMoisture = 0.0;
    float soilTemp = 0.0; // Assuming you have this
    int rainCount = 0;
    float windSpeed = 0.0;
    int windDirection = 0;
    
    // Power Monitoring (5 rails + Battery + Solar)
    float volt_3v3 = 0.0;
    float volt_5v = 0.0;
    float volt_batt = 0.0;
    float volt_solar = 0.0;
    float volt_dc = 0.0;
};

=======
#ifndef SENSOR_DATA_H
#define SENSOR_DATA_H

struct SensorData {
    float airPressure = 0.0;
    float altitude = 0.0;
    float temperature = 0.0; // From DHT or BME
    float humidity = 0.0;
    float lightLevel = 0.0;
    float soilMoisture = 0.0;
    float soilTemp = 0.0; // Assuming you have this
    int rainCount = 0;
    float windSpeed = 0.0;
    int windDirection = 0;
    
    // Power Monitoring (5 rails + Battery + Solar)
    float volt_3v3 = 0.0;
    float volt_5v = 0.0;
    float volt_batt = 0.0;
    float volt_solar = 0.0;
    float volt_dc = 0.0;
};

>>>>>>> 0a3d4a415a0e6c63afa63b2638ea703b80302390
#endif

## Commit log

2025-10-31 schematic version 1
    [AWS PROJECT.kicad_pcb, AWS PROJECT.kicad_sch, gateway.kicad_sch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]
2025-11-01 finalised schematic
    [AWS PROJECT.kicad_pcb, gateway.kicad_sch]
2025-11-03 first pcb draft
    [AWS PROJECT.kicad_pcb, AWS PROJECT.kicad_sch, gateway.kicad_sch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]
2025-11-06 finalised power schematic
    [gateway.kicad_sch, power.kicad_sch]
2025-11-14 commit 111
    [power.kicad_sch]
2025-12-19 algorirthim design start
    [AWS PROJECT.kicad_sch, gateway.kicad_sch, power.kicad_sch]
2025-12-19 Add lock file for schematic with hostname and username information
2025-12-19 Refactor code structure for improved readability and maintainability
    [gateway.kicad_sch]
2025-12-20 updates to the code and hardware, testing complete
    [gateway.kicad_sch]
2025-12-21 updates to gateway board
    [gateway.kicad_sch]
2025-12-26 updates to the power board
    [gateway.kicad_sch, power.kicad_sch]
2025-12-31 changes tp gateway bosrd
    [gateway.kicad_sch]
2025-12-31 updates to pcb color
2025-12-31 changes to schematic
    [AWS PROJECT.kicad_sch]
2026-01-01 All files
    Adding all files from local drive
    [AWS PROJECT.kicad_sch, gateway.kicad_sch, power.kicad_sch]
2026-01-01 re-organizing files
    organizing folders for readability
    [AWS PROJECT.kicad_sch, gateway.kicad_sch, power.kicad_sch]
2026-01-01 re-naming folders from local drive
    [AWS PROJECT.kicad_sch, gateway.kicad_sch, power.kicad_sch]
2026-01-01 assigning 3D foot prints
2026-01-01 adding system images for current design and previous design
2026-01-01 updating 3D footprints on PCB
    [AWS PROJECT.kicad_sch]
2026-01-02 BOM used for prototyping
    [BOM-Prototyping.xlsx]
2026-01-02 Added project reports
    [BOM prototyping.xlsx, COMPONENT LIST.xlsx]
2026-01-03 Prototype Report
    [BOM prototyping.xlsx]
2026-01-06 Implement wind speed and direction sensor classes; update DAVIS class for improved rain gauge functionality
2026-01-07 fixed i2c error on pcb, added power monitoring code, tested all i2c slaves
    [gateway.kicad_sch]
2026-01-07 updates to the gateway board
    [gateway.kicad_sch]
2026-01-07 cosmetic updates to pcb boards
    [gateway.kicad_sch]
2026-01-07 RESTRUCTURING FILES
    [AWS PROJECT.kicad_sch, gateway.kicad_sch, junction_box_asm.stp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]
2026-01-08 MODIFACTIONS TO CASE DESIGN
2026-01-08 adding vents to case
2026-01-19 footprints, text, logo alignment and report
    [power.kicad_sch]
2026-01-26 updates to gsm code, connected to things speak,
    [gateway.kicad_sch]
2026-01-28 changes to pcb and 3d mdel
    [gateway.kicad_sch]
2026-01-29 updates to board
2026-02-02 deleting documents from public
    [BOM prototyping.xlsx, COMPONENT LIST.xlsx]
2026-02-04 resolving merge
    [AWS PROJECT.kicad_sch, gateway.kicad_sch, junction_box_asm.stp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]
2026-02-04 Add research overview for AWS power electronics
    Added a detailed overview of the research on modular and adaptive power electronics for Automatic Weather Stations (AWS).
2026-02-04 Revise README for clarity on modular power system
    Updated the description of the modular power electronics system to clarify energy source integration and control strategy.
2026-02-16 edits to the boards, got lcsc part numbers for bom, swapped unavailable components, fixed net label confilcts
    [gateway.kicad_sch, power.kicad_sch]
2026-02-16 further updates to board
2026-02-21 updates to pcb board and creation of BOM
    [AWS PROJECT-B_Cu.gbr, AWS PROJECT-B_Mask.gbr, AWS PROJECT-B_Paste.gbr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]
2026-04-28 Revise README for clarity on project objectives
    Refined system description for the modular and adaptive power electronics architecture for AWS. Enhanced clarity and structure in outlining the project's goals, methodologies, and expected outcomes.
2026-06-23 All previous PCBA edits
    [AWS PROJECT.kicad_sch, gateway.kicad_sch, power.kicad_sch]
2026-06-23 clean up
    [AWS PROJECT.kicad_pcb, AWS PROJECT.kicad_sch, aws.kicad_pcb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]
2026-09-08 September update gerber files for first physical testing
    [AWS GATEWAY-B_Cu.gbr, AWS GATEWAY-B_Mask.gbr, AWS GATEWAY-B_Paste.gbr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]
2026-09-08 PCB Designs printed
    [AWS GATEWAY.kicad_pcb, AWS GATEWAY.kicad_sch, AWS POWER.kicad_pcb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]
2026-10-07 designs printed
    [AWS GATEWAY.kicad_pcb, AWS GATEWAY.kicad_sch, AWS POWER.kicad_pcb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]
2026-10-07 edit on page seetings/titles and version control
    [AWS GATEWAY-B_Cu.gbr, AWS GATEWAY-B_Mask.gbr, AWS GATEWAY-B_Paste.gbr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]
2026-10-07 BOM for ver 3 design
    [BOM-Prototyping.xlsx]
